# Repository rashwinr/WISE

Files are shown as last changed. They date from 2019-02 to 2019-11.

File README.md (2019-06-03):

# Wearable Inertial Sensors for Exergames

We are creating a wearable IMUs for ROM (range of motion) assessment and arm rehabilitation of stroke patients.

Data: The data folder consists of data sets saved from the IMU.
Arduino: All scripts relevant to the jacket are placed here.
3D model: All the IMU enclosure for the jacket are placed in this folder.

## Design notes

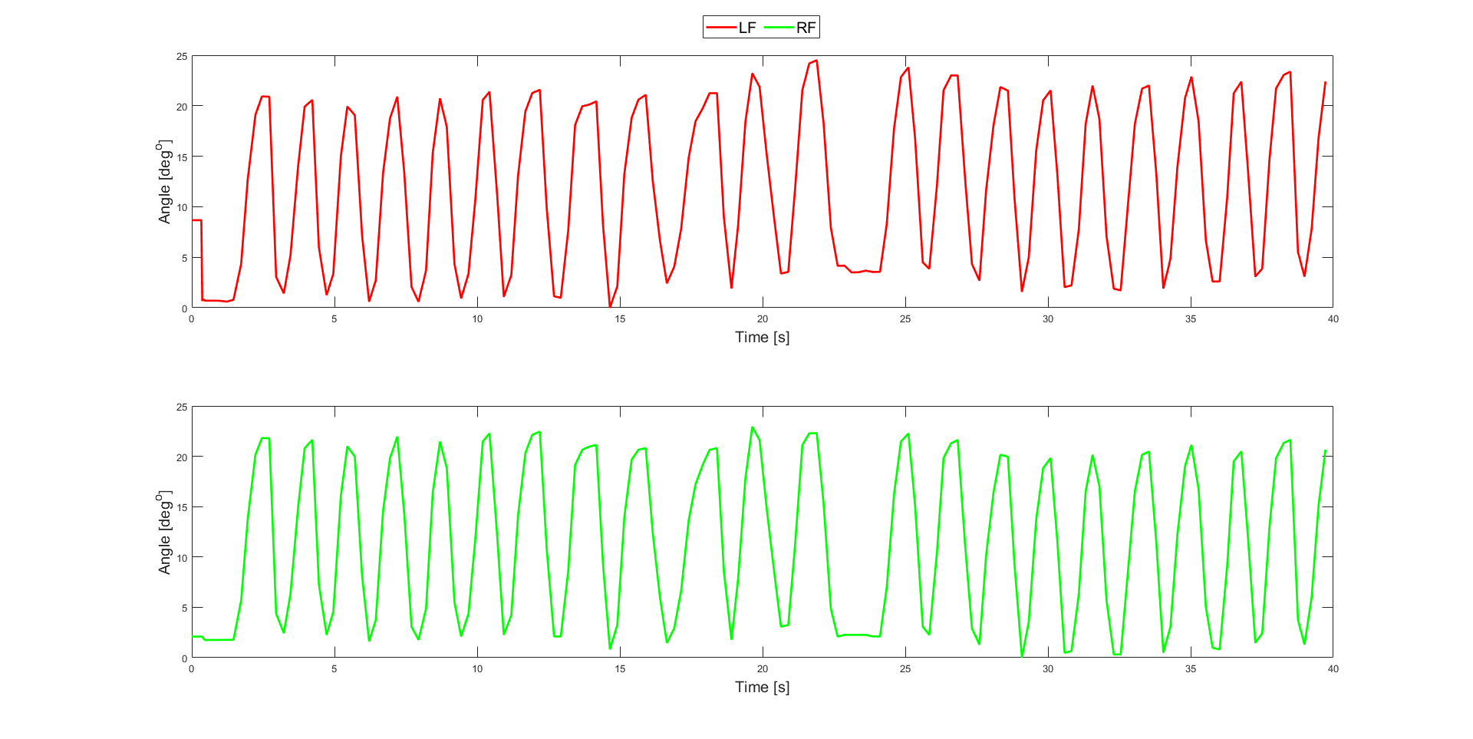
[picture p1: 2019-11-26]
matlab/IEEE_sensors/data_matched/LF,RF/Y/20 degrees.png

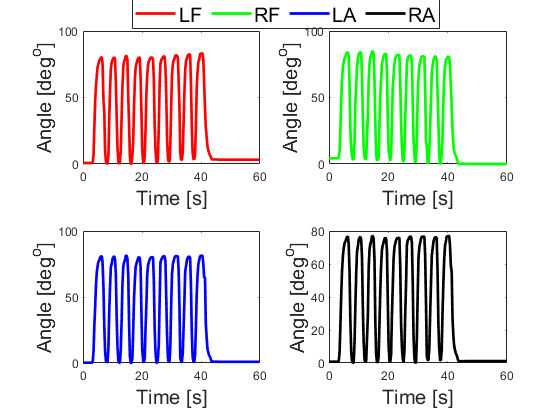
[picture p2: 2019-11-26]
matlab/IEEE_spmb/data_matched/A,B,C,D/Z/80 degress.png

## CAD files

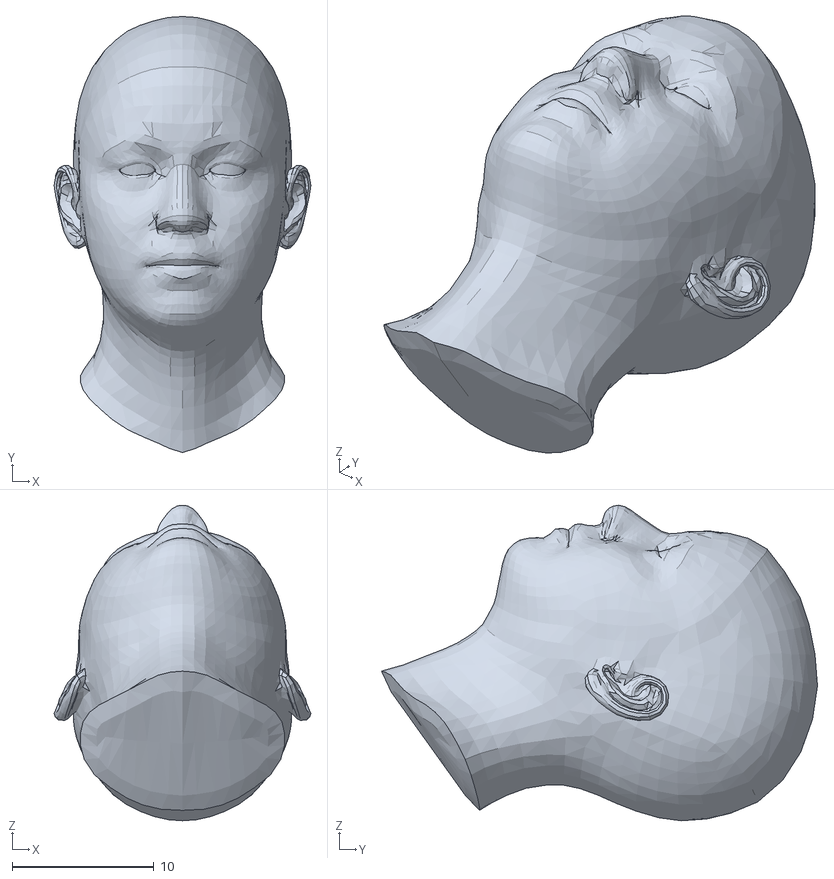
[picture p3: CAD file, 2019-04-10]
matlab/KInectProject/Kin2/Mex/NuiDatabase/HDFaceTracker/WholeHeadModel/fullMeanHead60_tri.ply
18.1 x 30.7 x 22.2

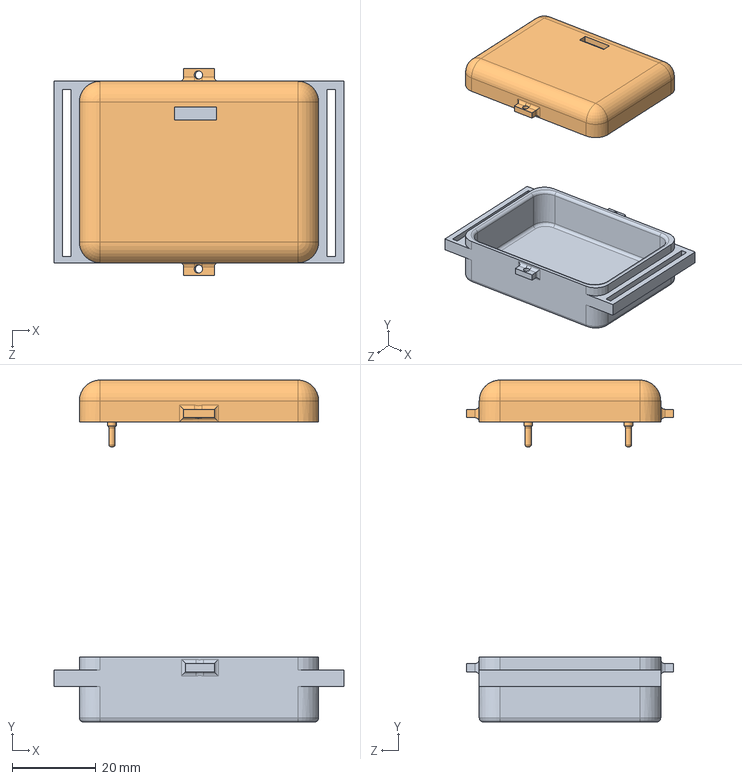
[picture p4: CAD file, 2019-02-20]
3D model/Assem1.SLDASM
69.3 x 81.9 x 49.5 mm
bottom_part_12_14_2018_Edited
top_part_12_14_2018_Edited

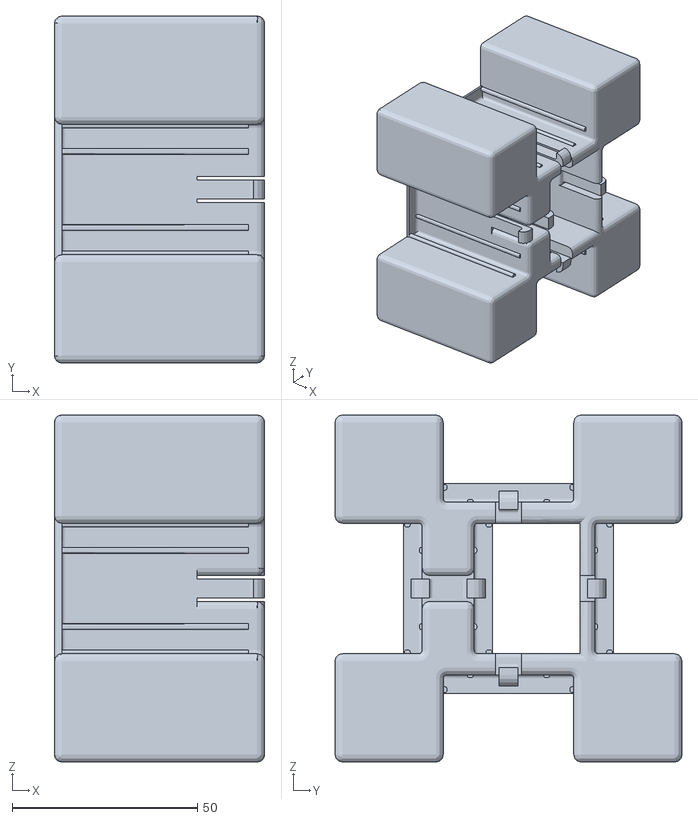
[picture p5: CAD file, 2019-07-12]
3d model final/calib_box.stl
56.7 x 93.6 x 93.6

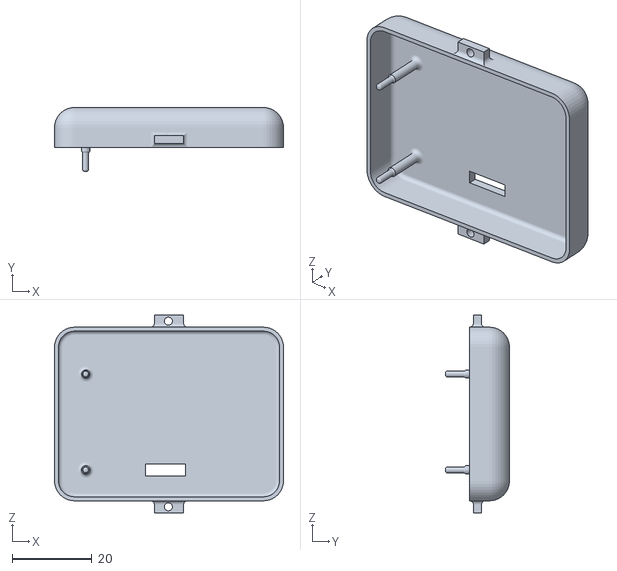
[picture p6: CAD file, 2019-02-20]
3D model/Assem1 - top_part_12_14_2018_Edited-1.STL
57.3 x 16.0 x 49.5

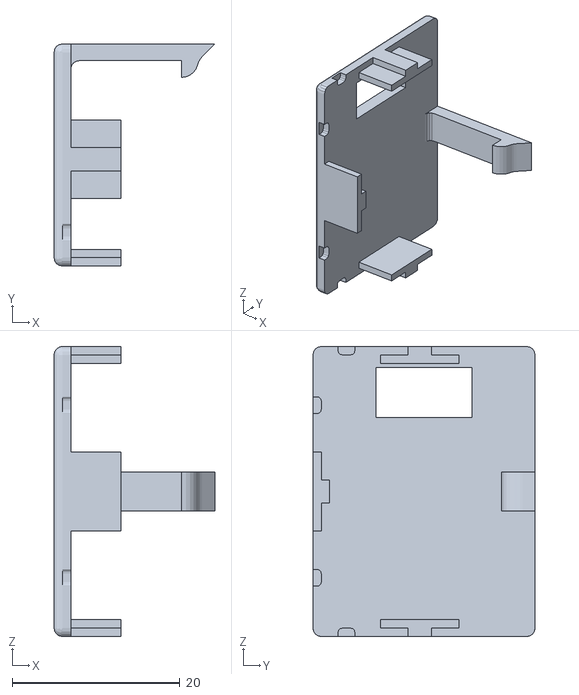
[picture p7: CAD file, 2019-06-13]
3Dmodel_ver4/door2.stl
19.2 x 26.5 x 34.6

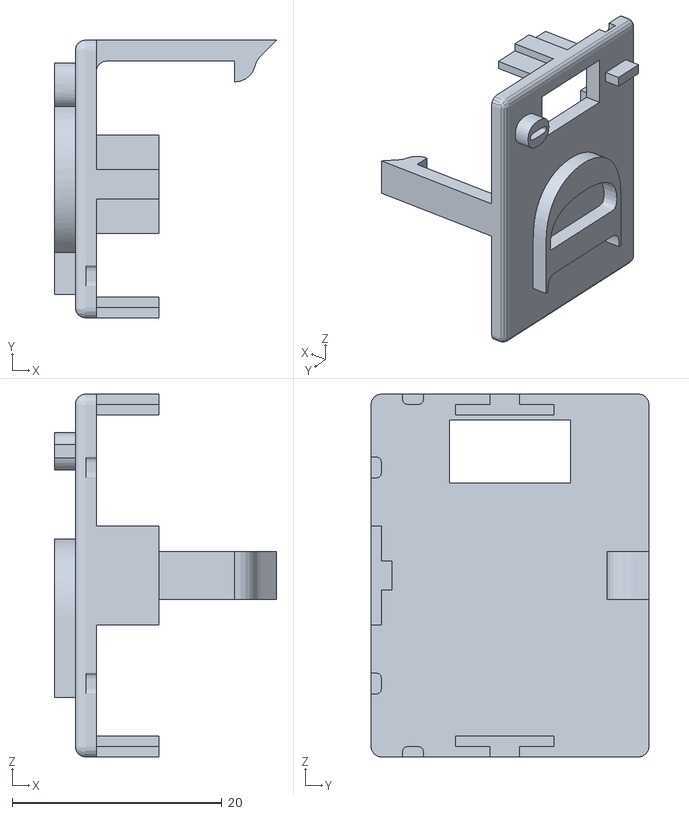
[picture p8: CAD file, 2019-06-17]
STL_4/D_door.stl
21.2 x 26.5 x 34.6

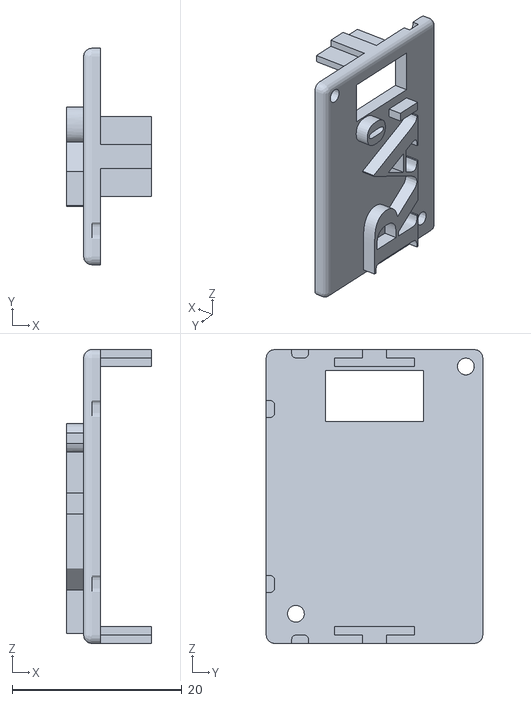
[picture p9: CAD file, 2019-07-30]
STL_4/WISE_design/door3_RA.stl
10.0 x 25.5 x 34.6

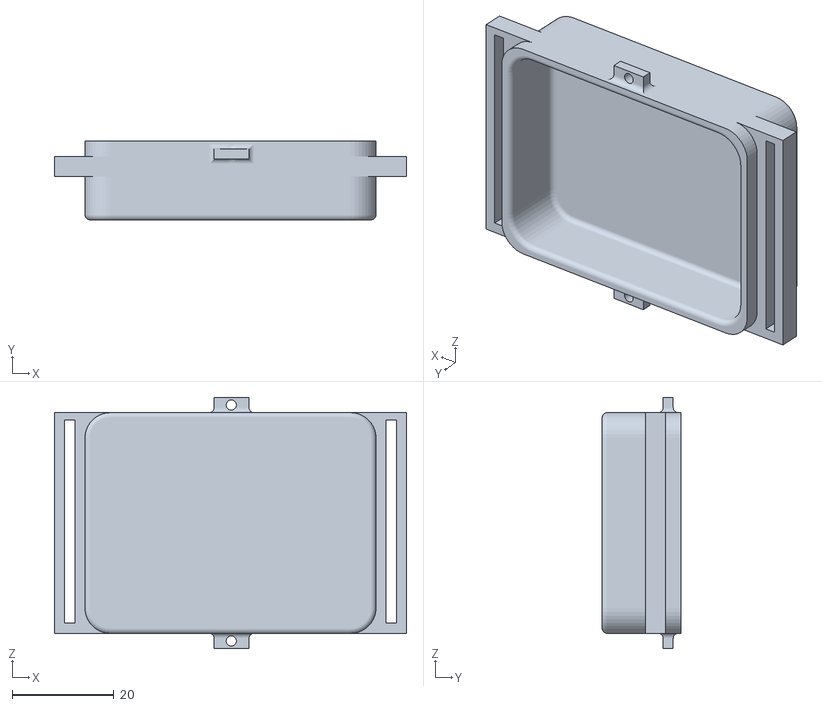
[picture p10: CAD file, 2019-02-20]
3D model/Assem1 - bottom_part_12_14_2018_Edited-1.STL
69.3 x 15.5 x 49.5

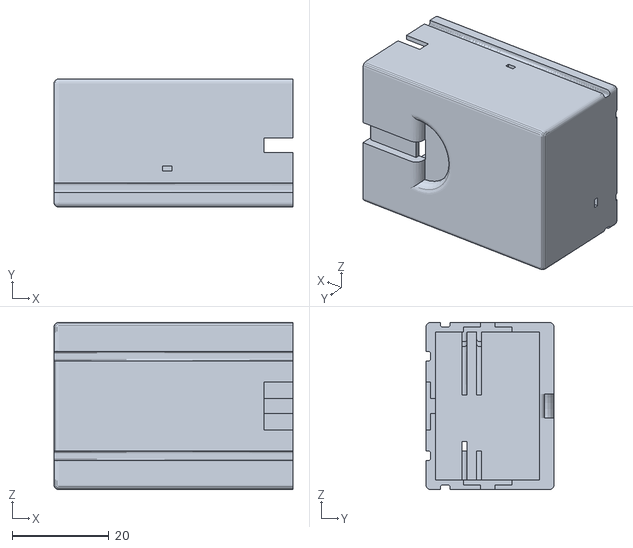
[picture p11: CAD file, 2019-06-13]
3Dmodel_ver4/case2.stl
49.4 x 26.5 x 34.6

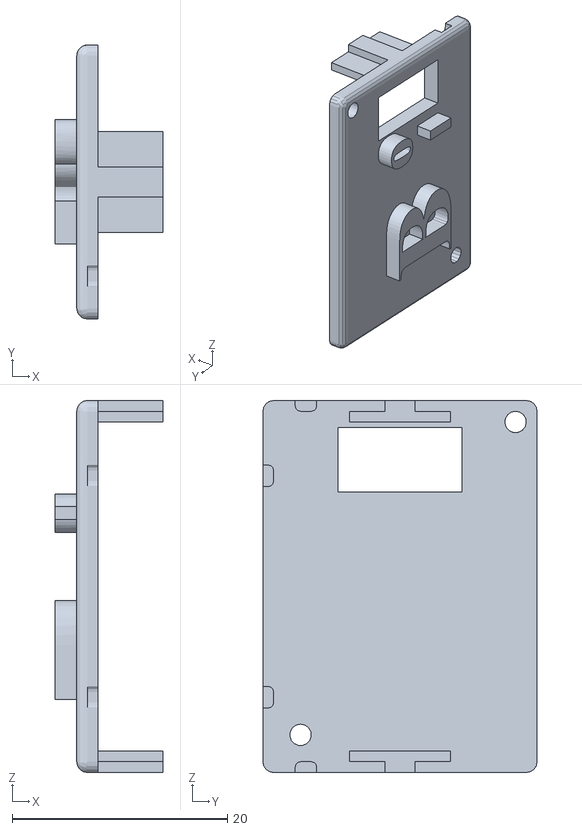
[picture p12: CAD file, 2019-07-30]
STL_4/WISE_design/door3_B.stl
10.0 x 25.5 x 34.6

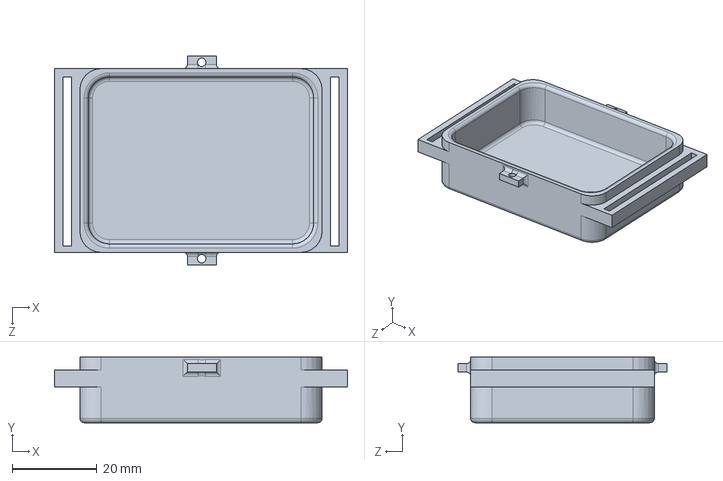
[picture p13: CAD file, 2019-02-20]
3D model/bottom_part_12_14_2018_Edited.SLDPRT
69.3 x 15.5 x 49.5 mm

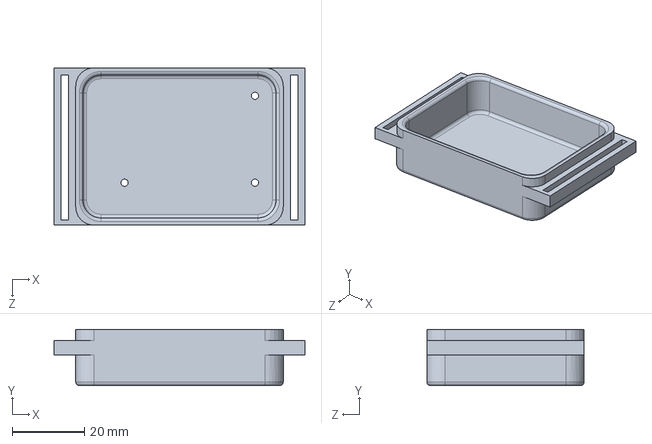
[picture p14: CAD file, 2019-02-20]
3D model/bottom_part_12_14_2018.SLDPRT
69.3 x 15.5 x 43.5 mm

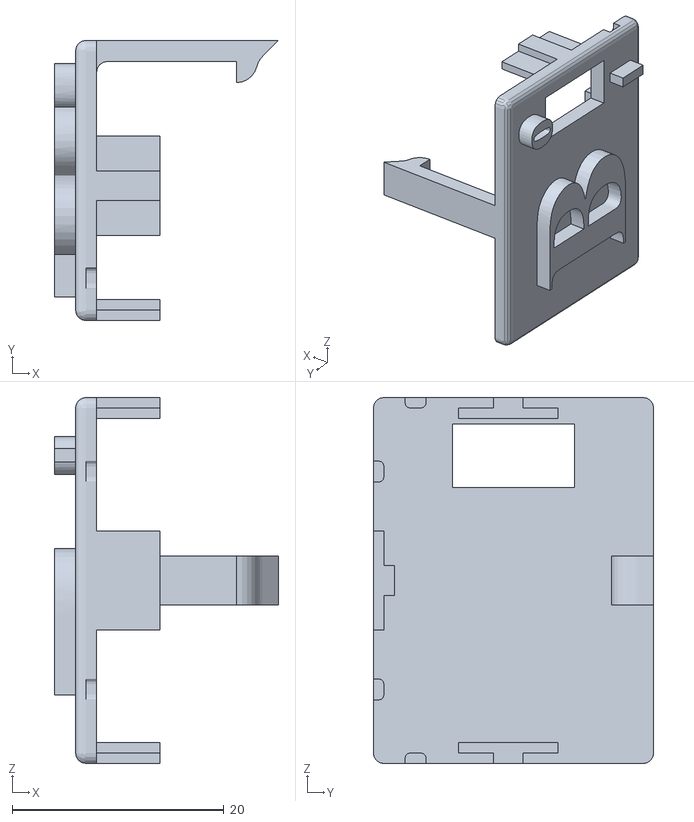
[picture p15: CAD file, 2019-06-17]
STL_4/B_door.stl
21.2 x 26.5 x 34.6

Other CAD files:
STL_4/XYZ_case.stl
STL_4/C_door.stl
STL_4/WISE_design/door3_RF.stl
STL_4/A_door.stl
STL_4/WISE_design/door3_LA.stl
3D model/bottom_part_12_14_2018.STL
3D model/bottom_part_12_14_2018_Edited.STL
3D model/top_part_12_14_2018.SLDPRT
3D model/top_part_12_14_2018.STL
3D model/top_part_12_14_2018_Edited.SLDPRT
3D model/top_part_12_14_2018_Edited.STL
3Dmodel_ver2/Assem1.SLDASM
3Dmodel_ver2/Assem1.SLDDRW
3Dmodel_ver2/bottom.SLDPRT
3Dmodel_ver2/bottom.STL
3Dmodel_ver2/box.SLDPRT
3Dmodel_ver2/calib_typ1_outsidebox.SLDPRT
3Dmodel_ver2/calibration_box.STL
3Dmodel_ver2/top.SLDPRT
3Dmodel_ver2/top.STL
3Dmodel_ver2/top_A.SLDPRT
3Dmodel_ver3/Assieme1.stl
3Dmodel_ver3/Assieme2.stl
3Dmodel_ver3/calibration_box.stl
3Dmodel_ver3/case.ipt
3Dmodel_ver3/case.stl
3Dmodel_ver3/door.ipt
3Dmodel_ver3/door.stl
3Dmodel_ver3/holderH.ipt
3Dmodel_ver3/holderH.stl
3Dmodel_ver3/holderV.ipt
3Dmodel_ver3/holderV.stl
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

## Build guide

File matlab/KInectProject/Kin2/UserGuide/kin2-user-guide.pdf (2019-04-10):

# Kin2. User Guide

### Juan R. Terven, Diana M. Cordova

## 1 Introduction

The Kin2 Toolbox for Matlab is an easy to use set of classes and functions that encapsulate the Microsoft Kinect 2 SDK. It is mostly based on C++ through mex files. The current version contains two classes and 30 functions divided in different features such as coordinate mapping, skeleton tracking, 3D reconstruc-

tion, and face gestures recognition.

## 2 Image Acquisition

Kinect three provides three sources of video images: RGB, depth, and infrared.

### The resolution of the RGB images is 1920 × 1080, the depth and infrared have

resolution of 512 × 424.

### The first step is to generate a Kin2 object specifying the image sources we

wish to obtain from the Kinect2. The available sources are color, depth,

### infrared and body. For example:

k2 = Kin2('color', 'depht', 'infrared')

### generates a Kin2 object named k2 that we can use to gather color, depth and/or

infrared frames from the Kinect2.

### To extract frames from the Kinect cameras we call the updateKin2 function on the Kin2 object. For example:

validData = k2.updateKin2

### Note that this function gets data from the Kinect and save it in an internal buffer

in Matlab. If there was a valid frame, the function returns 1 if not, returns 0.

### To actually get the frames in Matlab variables we call the corresponding

functions on the Kin2 object: getDepth, getColor, and getInfrared.

### Listing 1.1 shows how to create a Kin2 object to gather and display video from these three sources. In this example, we created we three figures, one for

each source and update the content each valid frame.

Listing 1.1. Kin2 initialization and data acquisition

1 | clear all
2 | % Create Kinect 2 object and initialize it
3 | % Select sources as input parameters.
4 | % Available sources: 'color', 'depth', 'infrared' and 'body'
5 | k2 = Kin2('color','depth','infrared');

6
7 % Create the figures for the images

8 | figure, h1 = imshow(zeros(424,512,'uint16'),[0 4000]);
9 | colormap('Jet'), colorbar;
10 | figure, h2 = imshow(zeros(1080,1920,3,'uint8'),[]);
11 | figure, h3 = imshow(zeros(424,512,'uint16'),[0 8000]);
12 | set(gcf,'keypress','k=get(gcf,''currentchar'');');

13
14 | % Loop until pressing 'q' on infrared figure
15 | k=[];
16 | while true
17 | % Read frames from Kinect
18 | validData = k2.updateData;

19
20 | % Before accessing the data,
21 | % make sure that a valid frame was acquired.
22 | if validData
23 | depth = k2.getDepth;
24 | color = k2.getColor;
25 | infrared = k2.getInfrared;

26
27 | set(h1,'CData',depth);
28 | set(h2,'CData',color);
29 | set(h3,'CData',infrared);
30 | end

31
32 | % If user presses 'q', on the infrared figure exit loop
33 | if ¬isempty(k)
34 | if strcmp(k,'q'); break; end;
35 | end

36
37 | pause(0.02)
38 | end

39
40 close all

41
42 | % Close kinect object
43 | k2.delete;

## 3 Coordinate Mapping

### Coordinate Mapping is used to perform two tasks [1]: (1) map between locations on the depth image and their corresponding locations on the color image and viceversa and (2) project and unproject from 2D image space to 3D camera

space. 2D image space refers to the depth or color image coordinates.

### In practice, to perform any mapping, you should always update the Kin2 data calling updateKin2 on the Kin2 object and see if there are valid data as

shown in listing 1.

### 3.1 Depth Space

### In depth space, x = 1, y = 1 corresponds to the top left corner of the image and x = 512, y = 424 is the bottom right corner of the image. When we need the

depth value or z, simply sample the depth image at the row/column in question,

### and use that value as z (in millimeters). For example: if depth is a depth image

obtained with getDepth, we get the depth as z = depth(row,col).

### Map Depth to Color The color sensor and depth sensor have a small offset between each other and different resolutions. To map between locations on the depth image and their corresponding locations on the color image Kin2 provides the function

ptColor = k2.mapDepthPoints2Color(ptDepth)
where ptColor and ptDepth are a n × 2 matrix of image coordinates.
For a complete code example see the mapping demo in section 7.1.

Map Depth to Camera and Point Cloud A common operation on the depth image is to generate a 3D point cloud of the scene. For this, Kin2 provides a couple of methods. The first one consists of mapping a set of coordinates from depth space to camera space for example. This method is useful if you only need to map few points from depth space to camera space:

ptCam = k2.mapDepthPoints2Camera(ptDepth)

### where ptDepth is a n×2 matrix (n x,y coordinates), and ptCam is n×3 matrix

(n x,y,z coordinates).

### If you want to get the complete point cloud, i.e. to map all the points from depth space to camera space, Kin2 provides:

pointCloud = k2.getPointCloud

### where pointcloud is a N × 3 camera space values. And N = 512 × 424 = 217088. Note that coordinates with no depth information can not be mapped to

camera space, and these coordinates are return as inf or -inf in camera space.

### For a complete code example see the camera mapping demo in section 7.3

and the point cloud demo in section 7.2.

### Map Depth to Infrared Depth and infrared images come from the same sensor so there is no offset and no change in resolution. To map a point from

depth to infrared just sample the same coordinates.

### 3.2 Color Space

In color space, x = 1, y = 1 corresponds to the top left corner of the image and x = 1920, y = 1080 is the bottom right corner of the image. A common practice in RGBD processing is to obtain the depth or world coordinates of specific color space coordinates. For example if we find features in the color image and we

want to know their depth or location in the world.

### Map Color to Depth Kin2 provides the following function to map from color

space to depth space.

ptDepth = k2.mapColorPoints2Depth(ptColor)
where ptColor and ptDepth are a n × 2 matrix of image coordinates.
For a complete code example see the mapping demo in section 7.1.

### Map Color to Camera Kin2 also provides a function to map from color space

to camera space.

ptCam = k2.mapColorPoints2Camera(ptColor)

### where ptColor is a n×2 matrix (n x,y coordinates), and ptCam is n×3 matrix

(n x,y,z coordinates).
For a complete code example see the camera mapping demo in section 7.3.

### 3.3 Camera Space

Camera space refers to the 3D coordinate system (right-handed) used by Kinect.

### The coordinate system is defined as follows [1]:

### – The origin (x=0, y=0, z=0) is located at the center of the IR sensor on

Kinect.

### – X grows to the sensors left – Y grows up (note that this direction is based on the sensors tilt) – Z grows out in the direction the sensor is facing – 1 unit = 1 meter

### Kinect2 SDK provides mapping capabilities between camera space and depth

or color space that is 2D projections.

### Map Camera to Depth Kin2 provides a function to map from 3D camera coordinates to depth image coordinates:

ptDepth = k2.mapCameraPoints2Depth(ptCam)

### where ptCam is n × 3 matrix (n x,y,z coordinates) and ptDepth is a n × 2

matrix (n x,y coordinates).
For a complete code example see the camera mapping demo in section 7.3.

### Map Camera to Color Kin2 also provides a function to map from 3D camera

coordinates to color image coordinates.

ptColor = k2.mapCameraPoints2Color(ptCam)

### where ptCam is n × 3 matrix (n x,y,z coordinates) and ptColor is a n × 2

matrix (n x,y coordinates).
For a complete code example see the camera mapping demo in section 7.3.

## 4 Body Tracking

Kin2 provides easy access to Kinect 2 body tracking capabilities.

### To enable body tracking, you must indicate the body source when creating the Kin2 object. For example:

k2 = Kin2(’color’,’depth’,’body’)

### creates a Kin2 object capable of fetching color and depth frames and also body

tracking information.

### Then to get the body data Kin2 provides the function getBodies that you can call after updating the Kin2 data. For example:

bodies = k2.getBodies

### where bodies is a structure array with one element for each body (6 bodies maximum). Each element contains the following information:

### – Position: a 3x25 matrix containing the x,y,z of the 25 joints in camera space coordinates

– TrackingState: state of each joint. These can be: NotTracked=0, Inferred=1,

### or Tracked=2 – LeftHandState: state of the left hand – RightHandState: state of the right hand

### The RightHandState and LeftHandState properties provide information about the state of each of the player’s hands. You can use this information to determine if a player is interacting with an object in the title’s world [2]. The states

returned are: Open, Closed, Lasso, NotTracked, Unknown.

### Once you have the joints position in 3D space you can map them to depth or

color space for visualization using the mapCameraPoints2Depth or mapCameraPoints2Color

### functions described in section 3.3, for example:

posDepth = k2.mapCameraPoints2Depth(bodies(1).Position’)
posColor = k2.mapCameraPoints2Color(bodies(1).Position’)
For a complete example of body tracking see section 7.4.

### 4.1 Drawing Bodies

### Kin2 provides functions to draw the bodies on the depth image or the color

image freeing the developer from this tedious task.

### To draw bodies on depth or color image you can use the drawBodies function as follows:

k2.drawBodies(d.ax,bodies,’depth’,5,3,15)

### where the six parameters are the following:

1. Image axes. Figure axes obtained with Matlab axes function.
2. Bodies structure. Bodies returned by the getBodies function.
3. Destination image. ’depth’ or ’color’.
4. Joints’ size. Circle raddii.
5. Bones’ Thickness.
6. Hands’ Size.

For a complete example of body tracking and drawing see section 7.4.

## 5 Face Processing

Kin 2 provides two levels of face processing: simple face processing and HD face.

### 5.1 Simple Face Processing

### With this functionality We can detect and track the face and recognize eight facial properties listed in table 1. The getFaces method returns a MATLAB structure array containing the following face data for each detected face:

– FaceBox: rectangle containing the user’s face.
– FacePoints: five alignment points located on the user’s face.
– FaceRotation: face orientation expressed as Euler angles: pitch, yaw, roll.

### – FaceProperties: read-only key/value pairs. See Table 1 for a description

of each property. Each property can have the following values: Unknown,
No, Maybe, or Yes.

Table 1. Face Properties contained in the FaceProperties field of the structure array returned with getFaces.

Name | Description
Happy | The user is showing a smile.

Engaged

Combines results from Looking Away and Eye Closed to determine if user is engaged with content.

WearingGlasses | The user is wearing glasses.
LeftEyeClosed | The user’s left eye is closed.
RightEyeClosed | The user’s right eye is closed.
MouthOpen | The user’s mouth is open.
MouthMoved | The user’s mouth moved
LookingAway | Determines if the user is looking away from the content

### 5.2 HD Face Processing

HD Face provides amazing face processing capabilities: (1) face capture with 94 shape units and a high definition face model with 1347 mesh vertices, (2) face tracking of 17 animation units (AUs) expressed as a numeric weight varying between 0 and 1. Kin2 provides access to these HD face capabilities with the getHDFaces method. This method returns a structure array containing the following fields for each detected face:

– FaceBox: rectangle containing the user’s face.
– FaceRotation: face orientation expressed as Euler angles: pitch, yaw, roll.

### – HeadPivot: center of the head, which the face may be rotated around. The origin is located at the Kinect’s optical center, the Z axis is pointing towards a user, the Y axis is pointing up and the X axis is pointing to the right. The

units are in meters.

### – AnimationUnits: 17 animation units (AUs) expressed as a numeric weight

varying between 0 and 1. Refer to [3] for a list of these animation units.

### – ShapeUnits: 94 shape units (SUs) expressed as a numeric weight varying between -2 and +2. Refer to [4] for a list of these shape units, also called

shape deformations.

### – FaceModel: high definition face model with 1347 mesh vertices. Refer to [5]

for a list of these high detail face points.

## 6 3D Reconstruction

### The Kin2 toolbox includes a version of Kinect Fusion taken from the Kinect for Windows SDK 2.0. To initialize the 3D reconstruction engine, Kin2 provides the method KF init that can be configured for different reconstruction’s resolution and size. The method prototype is the following:

KF init(voxelsPerMeter,voxelsX,voxelsY,voxelsZ,gpu)

For example if we set voxelsPerMeter to 256 we will have a resolution of 1000mm ÷ 256vpm = 3.9mm/voxel, then if we set voxelsX, voxelsY, and voxelsZ to 384 we will have a reconstruction of 384voxels ÷ 256vpm = 1.5m wide reconstruction and we will require at least 384 × 384 × 384 × 4 bytes per voxel = 227MB of memory. The final parameter gpu if true, the algorithm will

use the GPU otherwise, it will use the CPU.

### Once initialized, each call to KF update updates the volume reconstruction

with new views.

## 7 Complete Code examples

### 7.1 Mapping Demo

1 % MAPPINGDEMO Illustrates how to map points between depth ... and color images

2 | %
3 | % Usage:
4 | % | - Press 'd' to select 5 points on the depth image. ...
| | The selected points
5 | % | will be mapped from depth to color and will be ...
| | displayed on both
6 | % | images in red.

7 | % | - Press 'c' to select 5 point on the color image. The ...
| | selected points
8 | % | will be mapped from color to depth and will be ...
| | displayed on both
9 | % | images in green.
10 | % | - Press 'q' to exit.
11 | %
12 | % Juan R. Terven, October 2015.
13 | % jrterven@hotmail.com

14
15 | addpath('Mex');
16 | clear all
17 | close all

18
19 | % Create a Kin2 object and initialize it
20 | % Select sources as input parameters.
21 | % Available sources: 'color', 'depth', 'infrared' and 'body'
22 | k2 = Kin2('color','depth');

23
24 | % images sizes
25 | d_width = 512; d_height = 424; outOfRange = 4000;
26 | c_width = 1920; c_height = 1080;

27
28 | % Color image is to big, let's scale it down
29 | COL_SCALE = 0.5;

30
31 | % Create matrices for the images
32 | depth = zeros(d_height,d_width,'uint16');
33 | color = ...
| | zeros(c_height*COL_SCALE,c_width*COL_SCALE,3,'uint8');

34
35 | % Images used to draw the markers
36 | depthAdditions = zeros(d_height,d_width,3,'uint8');
37 | colorAdditions = ...
| | zeros(c_height*COL_SCALE,c_width*COL_SCALE,3,'uint8');

38
39 | % depth stream figure
40 | d.h = figure;
41 | d.ax = axes('units','pixels','drawmode','fast');
42 | d.im = imshow(depth,[0 255]);
43 | title('Depth Source (press q to exit)')
44 | set(gcf,'keypress','k=get(gcf,''currentchar'');'); % ...
| | listen keypress

45
46 | % color stream figure
47 | c.h = figure;
48 | c.im = imshow(color,[]);
49 | title('Color Source (press q to exit)');
50 | set(gcf,'keypress','k=get(gcf,''currentchar'');'); % ...
| | listen keypress

51

52
53 | % Loop until pressing 'q' on any figure
54 | k=[];

55
56 | disp('Instructions:')
57 | disp('Press d to select a point on the depth image')
58 | disp('Press c to select a point on the color image')
59 | disp('Press q on any figure to exit')

60
61 | while true
62 | % Get frames from Kinect and save them on underlying ...
| buffer
63 | validData = k2.updateData;

64
65 | % Before processing the data, we need to make sure ...
| that a valid
66 | % frame was acquired.
67 | if validData
68 | % Copy data to Matlab matrices
69 | depth = k2.getDepth;
70 | color = k2.getColor;

71
72 | % update depth figure
73 | depth8u = uint8(depth*(255/outOfRange));
74 | depth8uc3 = repmat(depth8u,[1 1 3]);
75 | set(d.im,'CData',depth8uc3 + depthAdditions);

76
77 | % update color figure
78 | color = imresize(color,COL_SCALE);
79 | set(c.im,'CData',color + colorAdditions);
80 | end

81
82 | % If user presses 'd' enter to points selection mode ...
| on the depth image
83 | % If user presses 'c' enter to points selection mode ...
| on the color image
84 | % If user presses 'q', exit loop
85 | if ¬isempty(k)
86 | if strcmp(k,'d')
87 | figure(d.h);
88 | title('Clic the image to sample 5 points');

89
90 | % Grab 5 points
91 | [x,y] = ginput(5);
92 | disp('Input depth coordinates');
93 | disp([x y])
94 | % Draw the selected points in the depth image

95 | depthAdditions = ...
| insertMarker(depthAdditions,[x ...
| y],'Color','red');

96
97 | % Using the mapping, map the points from ...
| depth coordinates to color coordinates
98 | % Input and output: n x 2 matrix (n points)
99 | colorCoords = k2.mapDepthPoints2Color([x y]);
100 | colorCoords = colorCoords * COL_SCALE; % ...
| scale the color coordinates

101
102 | disp('Output color coordinates');
103 | disp(colorCoords);

104
105 | % Draw the output coordinates on the color image
106 | colorAdditions = insertMarker(colorAdditions, ...
| colorCoords,'Color','red','Size',10);

107
108 | k = [];
109 | elseif strcmp(k,'c')
110 | figure(c.h);
111 | title('Clic the image to sample 5 points');

112
113 | % Grab 5 points
114 | [x,y] = ginput(5);
115 | disp('Input color coordinates');
116 | disp([x y]);

117
118 | % Draw the selected points in the color image
119 | colorAdditions = ...
| insertMarker(colorAdditions,[x ...
| y],'Color','green','Size',5);

120
121 | % Using the mapping, map the points from ...
| color coordinates to depth coordinates
122 | % Input and output: n x 2 matrix (n points)
123 | depthCoords = ...
| k2.mapColorPoints2Depth([x/COL_SCALE ...
| y/COL_SCALE]);

124
125 | disp('Output depth coordinates')
126 | disp(depthCoords);

127
128 | % Drae the output coordinates on the depth image
129 | depthAdditions = ...
| insertMarker(depthAdditions,depthCoords,'Color','green');

130

131
132 | k = [];
133 | end

134
135 | if strcmp(k,'q'); break; end;
136 | end

137
138 | pause(0.02)
139 | end

140
141 | % Close kinect object
142 | k2.delete;

143
144 close all

### 7.2 Point Cloud Demo

1 | % POINTCLOUDDEMO Illustrates how to use the Kin2 class to ...
| get the
2 | % pointcloud in camera space
3 | %
4 | % Juan R. Terven, January 2016.
5 | % jrterven@hotmail.com

6
7 | addpath('Mex');
8 | clear all
9 | close all

10
11 | % Create Kinect 2 object and initialize it
12 | % Select sources as input parameters.
13 | % Available sources: 'color', 'depth', 'infrared' and 'body'
14 | k2 = Kin2('depth');

15
16 | % images sizes
17 | depth_width = 512; depth_height = 424; outOfRange = 4000;

18

19
20 | % Create matrices for the images
21 | depth = zeros(depth_height,depth_width,'uint16');
22 | pointCloud = zeros(depth_height*depth_width,3);

23
24 | % depth stream figure
25 | figure, h1 = imshow(depth,[0 outOfRange]);
26 | title('Depth Source (press q to exit)')
27 | colormap('Jet')
28 | colorbar
29 | set(gcf,'keypress','k=get(gcf,''currentchar'');'); % ...
| listen keypress

30
31 % point cloud figure

32 | figure, hpc = ...
| plot3(pointCloud(:,1),pointCloud(:,2),pointCloud(:,3),'.');
33 | title('Point Cloud (press q to exit)')
34 | axis([-3 3 -3 3 0 4])
35 | xlabel('X'), ylabel('Y'), zlabel('Z');
36 | set(gcf,'keypress','k=get(gcf,''currentchar'');'); % ...
| listen keypress

37
38 | % Loop until pressing 'q' on any figure
39 | k=[];

40
41 | disp('Press q on any figure to exit')
42 | while true
43 | % Get frames from Kinect and save them on underlying ...
| buffer
44 | validData = k2.updateData;

45
46 | % Before processing the data, we need to make sure ...
| that a valid
47 | % frame was acquired.
48 | if validData
49 | % Copy data to Matlab matrices
50 | depth = k2.getDepth;

51
52 | % update depth figure
53 | depth(depth>outOfRange) = outOfRange; % truncate ...
| depht
54 | set(h1,'CData',depth);

55
56 | pointCloud = k2.getPointCloud;
57 | set(hpc,'XData',pointCloud(:,1),'YData',pointCloud(:,2),'ZData',pointCloud(:,3));

58
59 | end

60
61 | % If user presses 'q', exit loop
62 | if ¬isempty(k)
63 | if strcmp(k,'q');
64 | break;
65 | elseif strcmp(k,'p');
66 | pause;
67 | end;
68 | end

69
70 | pause(0.02)
71 | end

72
73 | % Close kinect object
74 | k2.delete;

75
76 close all;

### 7.3 Camera Mapping Demo

1 % MAPPINGTOCAMDEMO Illustrates how to map points between ... depth and color images

2 | %
3 | % Usage:
4 | % | - Press 'd' to select a point on the depth image. The ...
| | selected point
5 | % | will be mapped from depth to camera and the ...
| | resulting coordinates are
6 | % | printed on command window. Then the camera ...
| | coordinates are mapped
7 | % | back to depth space and printed to command window.
8 | % | - Press 'c' to select a point on the color image. The ...
| | selected point
9 | % | will be mapped from color to camera and the ...
| | resulting coordinates are
10 | % | printed on command window. | Then the camera ...
| | coordinates are mapped
11 | % | back to color space and printed to command window.
12 | % | - Press 'q' to exit.
13 | %
14 | % Juan R. Terven, October 2015.
15 | % jrterven@hotmail.com

16
17 | addpath('Mex');
18 | clear all
19 | close all

20
21 | % Create Kinect 2 object and initialize it
22 | % Select sources as input parameters.
23 | % Available sources: 'color', 'depth', 'infrared' and 'body'
24 | k2 = Kin2('color','depth');

25
26 | % images sizes
27 | depth_width = 512; depth_height = 424; outOfRange = 4000;
28 | color_width = 1920; color_height = 1080;

29
30 | % Color image is to big, let's scale it down
31 | COL_SCALE = 0.5;

32
33 | % Create matrices for the images
34 | depth = zeros(depth_height,depth_width,'uint16');
35 | color = ...
zeros(color_height*COL_SCALE,color_width*COL_SCALE,3,'uint8');

36
37 | % Images used to draw the markers
38 | depthAdditions = zeros(depth_height,depth_width,3,'uint8');
39 | colorAdditions = ...
| zeros(color_height*COL_SCALE,color_width*COL_SCALE,3,'uint8');

40
41 | % depth stream figure
42 | h1 = figure;
43 | hdepth = imshow(depth,[0 255]);
44 | title('Depth Source (press q to exit)')
45 | set(gcf,'keypress','k=get(gcf,''currentchar'');'); % ...
| listen keypress

46
47 | % color stream figure
48 | h2 = figure;
49 | hcolor = imshow(color,[]);
50 | title('Color Source (press q to exit)');
51 | set(gcf,'keypress','k=get(gcf,''currentchar'');'); % ...
| listen keypress

52

53
54 | % Loop until pressing 'q' on any figure
55 | k=[];

56
57 | disp('Instructions:')
58 | disp('Press d to select a point on the depth image')
59 | disp('Press c to select a point on the color image')
60 | disp('Press q on any figure to exit')

61
62 | while true
63 | % Get frames from Kinect and save them on underlying ...
| buffer
64 | validData = k2.updateData;

65
66 | % Before processing the data, we need to make sure ...
| that a valid
67 | % frame was acquired.
68 | if validData
69 | % Copy data to Matlab matrices
70 | depth = k2.getDepth;
71 | color = k2.getColor;

72
73 | % update depth figure
74 | depth8u = uint8(depth*(255/outOfRange));
75 | depth8uc3 = repmat(depth8u,[1 1 3]);
76 | set(hdepth,'CData',depth8uc3 + depthAdditions);

77
78 | % update color figure
79 | color = imresize(color,COL_SCALE);
80 | set(hcolor,'CData',color + colorAdditions);

81 | end

82
83 | % If user presses 'd' enter to points selection mode ...
| on the depth image
84 | % If user presses 'c' enter to points selection mode ...
| on the color image
85 | % If user presses 'q', exit loop
86 | if ¬isempty(k)
87 | if strcmp(k,'d')
88 | figure(h1);
89 | title('Clic the image to sample a point');

90
91 | % Grab 1 points
92 | [x,y] = ginput(1);
93 | disp('Input depth coordinates');
94 | disp([x y])
95 | % Draw the selected points in the depth image
96 | depthAdditions = ...
| insertMarker(depthAdditions,[x ...
| y],'Color','red');

97
98 | % Map the point from depth coordinates to ...
| camera coordinates
99 | % Input: 1 x 2 matrix (1 points, x,y)
100 | % Output: 1 x 3 matrix (1 point, x,y,z)
101 | camCoords = k2.mapDepthPoints2Camera([x y]);

102
103 | disp('Mapped camera coordinates');
104 | disp(camCoords);

105
106 | % Map the resulting camera point back to ...
| depth space
107 | depthCoords = ...
| k2.mapCameraPoints2Depth(camCoords);
108 | disp('Mapped depth coordinates');
109 | disp(depthCoords);

110
111 | k = [];
112 | elseif strcmp(k,'c')
113 | figure(h2);
114 | title('Clic the image to sample 5 points');

115
116 | % Grab 1 point
117 | [x,y] = ginput(1);
118 | disp('Input color coordinates');
119 | disp([x/COL_SCALE y/COL_SCALE]);

120
121 | % Draw the selected point in the color image

122 | colorAdditions = ...
| insertMarker(colorAdditions,[x ...
| y],'Color','green','Size',5);

123
124 | % Map the points from color coordinates to ...
| camera coordinates
125 | % Input: 1 x 2 matrix (1 points, x,y)
126 | % Output: 1 x 3 matrix (1 point, x,y,z)
127 | camCoords = ...
| k2.mapColorPoints2Camera([x/COL_SCALE ...
| y/COL_SCALE]);

128
129 | disp('Mapped camera coordinates')
130 | disp(camCoords);

131
132 | % Map the resulting camera point back to ...
| color space
133 | colorCoords = ...
| k2.mapCameraPoints2Color(camCoords);
134 | disp('Mapped color coordinates');
135 | disp(colorCoords);

136
137 | k = [];
138 | end

139
140 | if strcmp(k,'q'); break; end;
141 | end

142
143 | pause(0.02)
144 | end

145
146 | % Close kinect object
147 | k2.delete;

148
149 close all

### 7.4 Body Tracking Demo

1 | % BODYDEMO Illustrates how to use the Kin2 object to get ...
| and draw the
2 | % Skeleton data
3 | %
4 | % Juan R. Terven, October 31 2015.
5 | % jrterven@hotmail.com

6
7 | addpath('Mex');
8 | clear all

9 close all

10
11 | % Create Kinect 2 object and initialize it
12 | % Select sources as input parameters.
13 | % Available sources: 'color', 'depth', 'infrared' and 'body'
14 | k2 = Kin2('color','depth','body');

15
16 | % images sizes
17 | d_width = 512; d_height = 424; outOfRange = 4000;
18 | c_width = 1920; c_height = 1080;

19
20 | % Color image is to big, let's scale it down
21 | COL_SCALE = 1.0;

22
23 | % Create matrices for the images
24 | depth = zeros(d_height,d_width,'uint16');
25 | color = ...
| zeros(c_height*COL_SCALE,c_width*COL_SCALE,3,'uint8');

26
27 | % depth stream figure
28 | d.h = figure;
29 | d.ax = axes('drawmode','fast');
30 | d.im = imshow(zeros(d_height,d_width,'uint8'));
31 | %hold on;

32
33 | title('Depth Source (press q to exit)')
34 | set(gcf,'keypress','k=get(gcf,''currentchar'');'); % ...
| listen keypress

35
36 | % color stream figure
37 | c.h = figure;
38 | c.ax = axes;
39 | c.im = imshow(color,[]);
40 | title('Color Source (press q to exit)');
41 | set(gcf,'keypress','k=get(gcf,''currentchar'');'); % ...
| listen keypress
42 | %hold on

43
44 | % Loop until pressing 'q' on any figure
45 | k=[];

46
47 | disp('Press q on any figure to exit')
48 | while true
49 | % Get frames from Kinect and save them on underlying ...
| buffer
50 | validData = k2.updateData;

51
52 | % Before processing the data, we need to make sure ...
| that a valid
53 | % frame was acquired.

54 | if validData
55 | % Copy data to Matlab matrices
56 | depth = k2.getDepth;
57 | color = k2.getColor;

58
59 | % update depth figure
60 | depth8u = uint8(depth*(255/outOfRange));
61 | depth8uc3 = repmat(depth8u,[1 1 3]);
62 | d.im = imshow(depth8uc3, 'Parent', d.ax);

63
64 | %set(d.im,'CData',depth8uc3);

65
66 | % update color figure
67 | color = imresize(color,COL_SCALE);
68 | c.im = imshow(color, 'Parent', c.ax);

69
70 | %set(c.im,'CData',color);

71
72 | % Get 3D bodies joints
73 | % getBodies returns a structure array.
74 | % The structure array (bodies) contains 6 bodies ...
at most
75 | % Each body has:
76 | % -Position: 3x25 matrix containing the x,y,z of ...
the 25 joints in
77 | % | camera space coordinates
78 | % -TrackingState: state of each joint. These can be:
79 | % | NotTracked=0, Inferred=1, or Tracked=2
80 | % -LeftHandState: state of the left hand
81 | % -RightHandState: state of the right hand
82 | bodies = k2.getBodies;

83
84 | % Number of bodies detected
85 | numBodies = size(bodies,2);
86 | disp(['Bodies Detected: ' num2str(numBodies)])

87
88 | % first body info:
89 | %disp(bodies(1).TrackingState)
90 | %disp(bodies(1).RightHandState)
91 | %disp(bodies(1).LeftHandState)

92
93 | % To get the joints on depth image space, you can ...
| | use:
94 | %pos2D = ...
| | k2.mapCameraPoints2Depth(bodies(1).Position');

95
96 | %To get the joints on color image space, you can use:
97 | %pos2D = ...
| | k2.mapCameraPoints2Color(bodies(1).Position');

98

99 | % Draw bodies on depth image
100 | % Parameters:
101 | % 1) image axes
102 | % 2) bodies structure
103 | % 3) Destination image (depth or color)
104 | % 4) Joints' size (circle raddii)
105 | % 5) Bones' Thickness
106 | % 6) Hands' Size
107 | k2.drawBodies(d.ax,bodies,'depth',5,3,15);

108
109 | % Draw bodies on color image
110 | k2.drawBodies(c.ax,bodies,'color',10,6,30);

111

112 | end

113
114 | % If user presses 'q', exit loop
115 | if ¬isempty(k)
116 | if strcmp(k,'q'); break; end;
117 | end

118
119 | pause(0.02)
120 | end

121
122 | % Close kinect object
123 | k2.delete;

124
125 close all;

### 7.5 Face Processing Demo

1 % FACEDEMO Illustrates how to use the Kin2 object to get ... and draw the
2 | % face data
3 | %
4 | % Note: You must add to the windows path the bin ...
| | directory containing the
5 | % | Kinect20.Face.dll.
6 | % | For example: C:\Program Files\Microsoft ...
| | SDKs\Kinect\v2.0_1409\bin
7 | %
8 | % Juan R. Terven, January 2016.
9 | % jrterven@hotmail.com

10
11 | addpath('Mex');
12 | clear all
13 | close all

14

15 | % Create Kinect 2 object and initialize it
16 | % Available sources: 'color', 'depth', 'infrared', ...
'body_index', 'body',
17 | % 'face' and 'HDface'
18 | k2 = Kin2('color','face');

19
20 | % images sizes
21 | c_width = 1920; c_height = 1080;

22
23 | % Color image is to big, let's scale it down
24 | COL_SCALE = 1.0;

25
26 | % Create matrices for the images
27 | color = ...
zeros(c_height*COL_SCALE,c_width*COL_SCALE,3,'uint8');

28
29 | % color stream figure
30 | c.h = figure;
31 | c.ax = axes;
32 | c.im = imshow(color,[]);
33 | title('Color Source (press q to exit)');
34 | set(gcf,'keypress','k=get(gcf,''currentchar'');'); % ...
listen keypress

35
36 | % Loop until pressing 'q' on any figure
37 | k=[];

38
39 | disp('Press q on any figure to exit')
40 | while true
41 | % Get frames from Kinect and save them on underlying ...
buffer
42 | validData = k2.updateData;

43
44 | % Before processing the data, we need to make sure ...
that a valid
45 | % frame was acquired.
46 | if validData
47 | % Get color frame
48 | color = k2.getColor;

49
50 | % Get the faces data
51 | % faces is a structure array with at most 6 ...
| | faces. Each face has
52 | % the following fields:
53 | % - FaceBox: rectangle coordinates representing ...
| | the face position in
54 | % | color space. [left, top, right, bottom].
55 | % - FacePoints: 2 x 5 matrix representing 5 face ...
| | landmarks:

56 | % | left eye, right eye, nose, right and left ...
| | mouth corners.
57 | % - FaceRotation: 1 x 3 vector containing: pitch, ...
| | yaw, roll angles
58 | % - FaceProperties: 1 x 8 vector containing the ...
| | detection result of
59 | % | each of the face properties.
60 | % | The face properties are:
61 | % | Happy, Engaged, WearingGlasses, ...
| | LeftEyeClosed, RightEyeClosed,
62 | % | MouthOpen, MouthMoved, LookingAway
63 | % | The detection results are:
64 | % | Unknown = 0, No = 1, Maybe = 2, Yes = 3;
65 | faces = k2.getFaces;

66
67 | % update color figure
68 | color = imresize(color,COL_SCALE);
69 | c.im = imshow(color, 'Parent', c.ax);

70
71 | % Display the faces data:
72 | % Parameters:
73 | % 1) image axes
74 | % 2) faces structure obtained with getFaces
75 | % 3) face landmarks size (radius)
76 | % 4) display text information?
77 | % 5) information font size in pixels
78 | k2.drawFaces(c.ax,faces,5,true,20);

79
80 | end

81
82 | % If user presses 'q', exit loop
83 | if ¬isempty(k)
84 | if strcmp(k,'q'); break; end;
85 | end

86
87 | pause(0.02)
88 | end

89
90 | % Close kinect object
91 | k2.delete;

92
93 close all;

### 7.6 HD Face Processing Demo

1 | % FACEHDDEMO Illustrates how to use the Kin2 object to ...
| get and display the

2 | % HD face data
3 | %
4 | % Note: You must add to the windows path the bin ...
| | directory containing the
5 | % | Kinect20.Face.dll.
6 | % | For example: C:\Program Files\Microsoft ...
| | SDKs\Kinect\v2.0_1409\bin
7 | %
8 | % Juan R. Terven, January 2016.
9 | % jrterven@hotmail.com

10
11 | addpath('Mex');
12 | clear all
13 | close all

14
15 | % Create Kinect 2 object and initialize it
16 | % Available sources: 'color', 'depth', 'infrared', ...
| | 'body_index', 'body',
17 | % 'face' and 'HDface'
18 | k2 = Kin2('color','HDface');

19
20 | % images sizes
21 | c_width = 1920; c_height = 1080;

22
23 | % Color image is to big, let's scale it down
24 | COL_SCALE = 1.0;

25
26 | % Create matrices for the images
27 | color = ...
| | zeros(c_height*COL_SCALE,c_width*COL_SCALE,3,'uint8');

28
29 | % color stream figure
30 | c.h = figure;
31 | c.ax = axes;
32 | c.im = imshow(color,[]);
33 | title('Color Source (press q to exit)');
34 | set(gcf,'keypress','k=get(gcf,''currentchar'');'); % ...
| | listen keypress

35
36 | model = zeros(3,1347);
37 | figure, hmodel = plot3(model(1,:),model(2,:),model(3,:),'.');
38 | %axis([-1 1 -1 1 -1 1])
39 | title('HD Face Model (press q to exit)')
40 | xlabel('X'), ylabel('Y'), zlabel('Z');
41 | set(gcf,'keypress','k=get(gcf,''currentchar'');'); % ...
| | listen keypress

42
43 | % Loop until pressing 'q' on any figure
44 | k=[];

45

46 | disp('Press q on any figure to exit')
47 | while true
48 | % Get frames from Kinect and save them on underlying ...
buffer
49 | validData = k2.updateData;

50
51 | % Before processing the data, we need to make sure ...
that a valid
52 | % frame was acquired.
53 | if validData
54 | % Get color frame
55 | color = k2.getColor;

56
57 | % update color figure
58 | color = imresize(color,COL_SCALE);
59 | c.im = imshow(color, 'Parent', c.ax);

60
61 | % Get the HDfaces data
62 | % the output faces is a structure array with at ...
| | most 6 faces. Each face has
63 | % the following fields:
64 | % - FaceBox: rectangle coordinates representing ...
| | the face position in
65 | % | color space. [left, top, right, bottom].
66 | % - FaceRotation: 1 x 3 vector containing: pitch, ...
| | yaw, roll angles
67 | % - HeadPivot: 1 x 3 vector, computed center of ...
| | the head,
68 | % | which the face may be rotated around.
69 | % | This point is defined in the Kinect body ...
| | coordinate system.
70 | % - AnimationUnits: 17 animation units (AUs). ...
| | Most of the AUs are
71 | % | expressed as a numeric weight varying between ...
| | 0 and 1.
72 | % | For details see ... https://msdn.microsoft.com/en-us/library/microsoft.kinect.face.faceshapeanimations.aspx
73 | % - ShapeUnits: 94 hape units (SUs). Each SU is ...
| | expressed as a
74 | % | numeric weight that typically varies between ...
| | -2 and +2.
75 | % | For details see ... https://msdn.microsoft.com/en-us/library/microsoft.kinect.face.faceshapedeformations.aspx
76 | % - FaceModel: 3 x 1347 points of a 3D face model ...
| | computed by face capture
77 | faces = k2.getHDFaces;

78
79 | % Display the HD faces data and face model(1347 ...
| | points):
80 | % Parameters:

81 | % 1) image axes
82 | % 2) faces structure obtained with getFaces
83 | % 3) display HD face model vertices(1347 points)?
84 | % 4) display text information (animation units)?
85 | % 5) text font size in pixels

86

87
88 | % Plot face model points
89 | if size(faces,2) > 0
90 | model = faces(1).FaceModel;
91 | set(hmodel,'XData',model(1,:),'YData',model(2,:),'ZData',model(3,:));
92 | end
93 | end

94
95 | % If user presses 'q', exit loop
96 | if ¬isempty(k)
97 | if strcmp(k,'q'); break; end;
98 | end

99
100 | pause(0.02)
101 | end

102
103 | % Close kinect object
104 | k2.delete;

105
106 close all;

### 7.7 Kinect Fusion Demo

1 % KINECTFUSIONDEMO Illustrates how to use the Kin2 to ... perform 3D
2 | % reconstruction
3 | %
4 | % Note: You must add to the windows path the bin ...
| | directory containing the
5 | % | Kinect20.Fusion.dll
6 | % | For example: C:\Program Files\Microsoft ...
| | SDKs\Kinect\v2.0_1409\bin
7 | %
8 | % Juan R. Terven, January 2016.
9 | % jrterven@hotmail.com

10
11 | addpath('../Mex');
12 | clear all
13 | close all

14
15 % Create Kinect 2 object and initialize it

16 | % Select sources as input parameters.
17 | % Available sources: 'color', 'depth', 'infrared', ...
| 'body_index', 'body',
18 | % 'face' and 'HDface'
19 | k2 = Kin2('color','depth');

20
21 k2.KF_init;

22
23 | % images sizes
24 | depth_width = 512; depth_height = 424; outOfRange = 4000;
25 | color_width = 1920; color_height = 1080;

26
27 | % Color image is to big, let's scale it down
28 | colorScale = 0.4;

29
30 | % Create matrices for the images
31 | depth = zeros(depth_height,depth_width,'uint16');
32 | volume = zeros(depth_height,depth_width,3,'uint8');
33 | color = ...
| zeros(color_height*colorScale,color_width*colorScale,3,'uint8');

34
35 | % depth stream figure
36 | figure, h1 = imshow(depth,[0 outOfRange]);
37 | title('Depth Source (press q to exit)')
38 | colormap('Jet')
39 | colorbar
40 | set(gcf,'keypress','k=get(gcf,''currentchar'');'); % ...
| listen keypress

41
42 | % color stream figure
43 | figure, h2 = imshow(color,[]);
44 | title('Color Source (press q to exit)');
45 | set(gcf,'keypress','k=get(gcf,''currentchar'');'); % ...
| listen keypress

46
47 | % volume stream figure
48 | figure, h3 = imshow(volume,[]);
49 | title('Volume Source (press q to exit)');
50 | set(gcf,'keypress','k=get(gcf,''currentchar'');'); % ...
| listen keypress

51
52 | % Loop until pressing 'q' on any figure
53 | k=[];
54 | timedFrames = zeros(1,100);
55 | disp('Press q on any figure to exit')
56 | for i=1:100
57 | tic
58 | % Get frames from Kinect and save them on underlying ...
| buffer
59 | validData = k2.updateData;

60
61 | % Before processing the data, we need to make sure ...
that a valid
62 | % frame was acquired.
63 | if validData
64 | % Copy data to Matlab matrices
65 | depth = k2.getDepth;
66 | color = k2.getColor;

67
68 | k2.KF_update;
69 | volume = k2.KF_getVolumeImage;

70
71 | % update depth figure
72 | depth(depth>outOfRange) = outOfRange; % truncate ...
| depht
73 | set(h1,'CData',depth);

74
75 | % update color figure
76 | color = imresize(color,colorScale);
77 | set(h2,'CData',color);

78
79 | % update infrared figure
80 | set(h3,'CData',volume);
81 | end

82
83 | % If user presses 'q', exit loop
84 | if ¬isempty(k)
85 | if strcmp(k,'q'); break; end;
86 | if strcmp(k,'m');
87 | mesh = k2.KF_getMesh;
88 | k=[];
89 | end;
90 | end

91
92 | pause(0.02)
93 | timedFrames(i) = toc;
94 | end

95
96 | % Close kinect object
97 | k2.delete;

98
99 close all;

## References

1. Microsoft: | Coordinate | mapping. | https://msdn.microsoft.com/en-
us/library/dn785530.aspx (January 2016)
2. Microsoft: | Body | tracking. | https://msdn.microsoft.com/en-
us/library/dn799273.aspx (January 2016)

3. Network, | M.D.: | Faceshapeanimations | enumera-
tion. | | https://msdn.microsoft.com/en-us/library/ | mi-
crosoft.kinect.face.faceshapeanimations.aspx (January 2016)
4. Network, | M.D.: | Faceshapedeformations | enumera-
tion. | | https://msdn.microsoft.com/en-us/library/ | mi-
crosoft.kinect.face.faceshapedeformations.aspx (January 2016)
5. Microsoft: | Highdetailfacepoints enumeration. | https://msdn.microsoft.com/en-
us/library/ microsoft.kinect.face.highdetailfacepoints.aspx (January 2016)

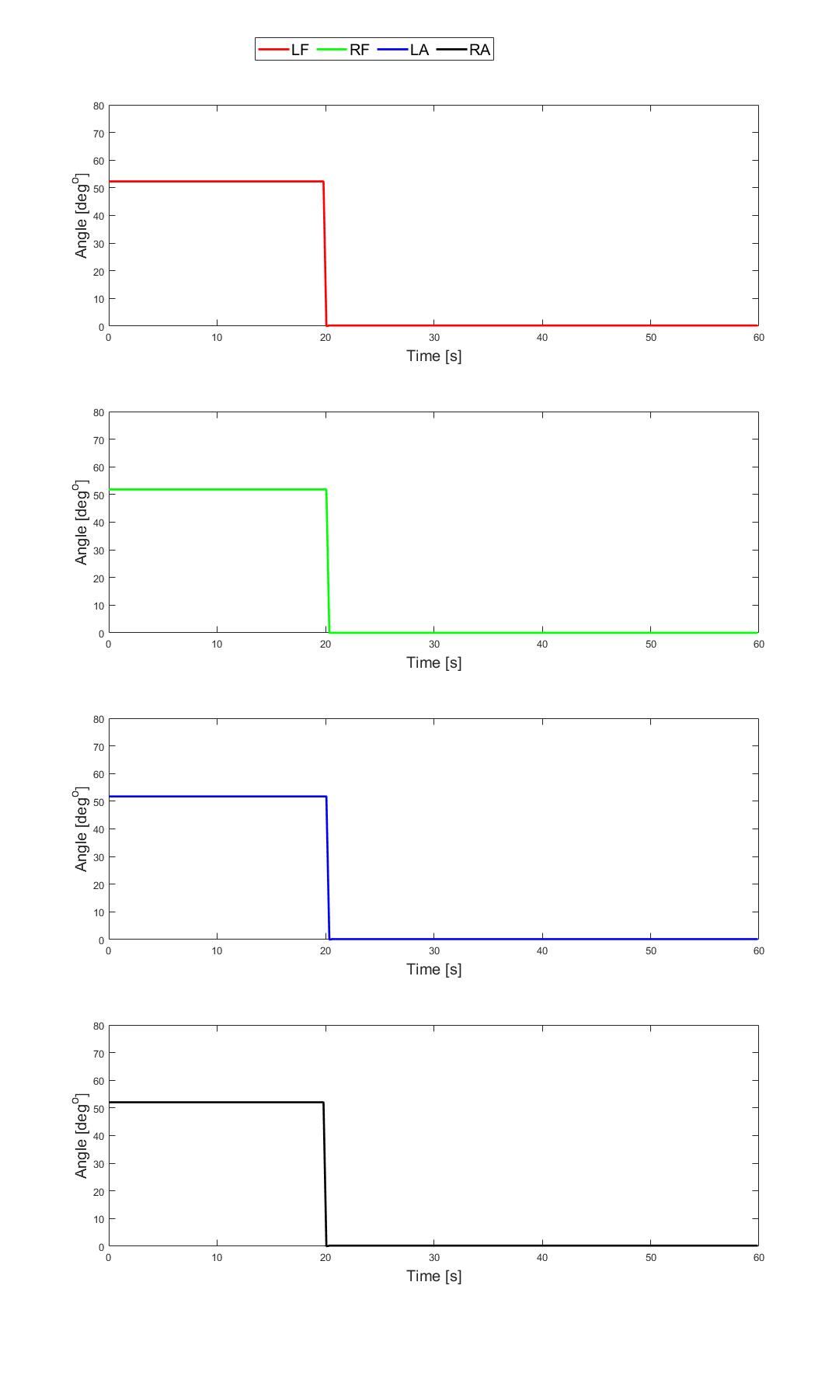
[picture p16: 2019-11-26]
matlab/IEEE_sensors/data_matched/LA,LF,RA,RF/Y/step down1.jpg

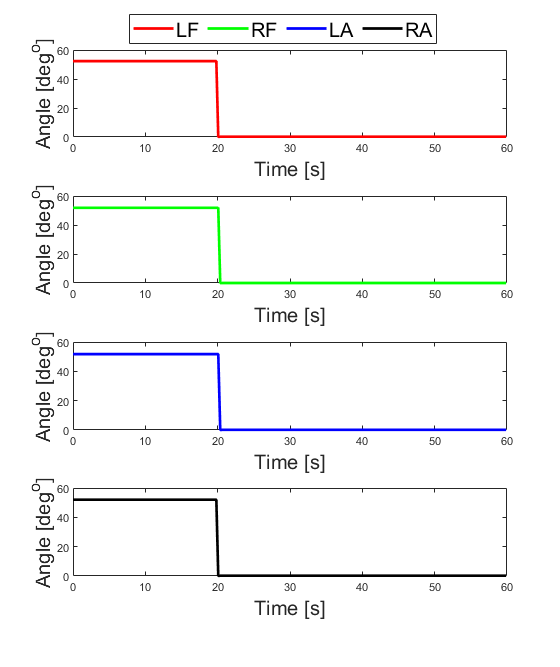
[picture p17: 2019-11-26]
matlab/IEEE_sensors/data_matched/LA,LF,RA,RF/Y/step down.png

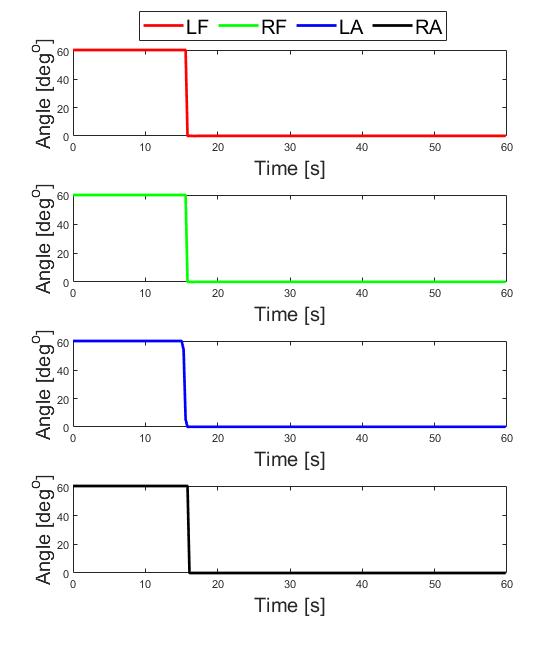
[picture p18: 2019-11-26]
matlab/IEEE_sensors/data_matched/LA,LF,RA,RF/Y/step down_60.jpg

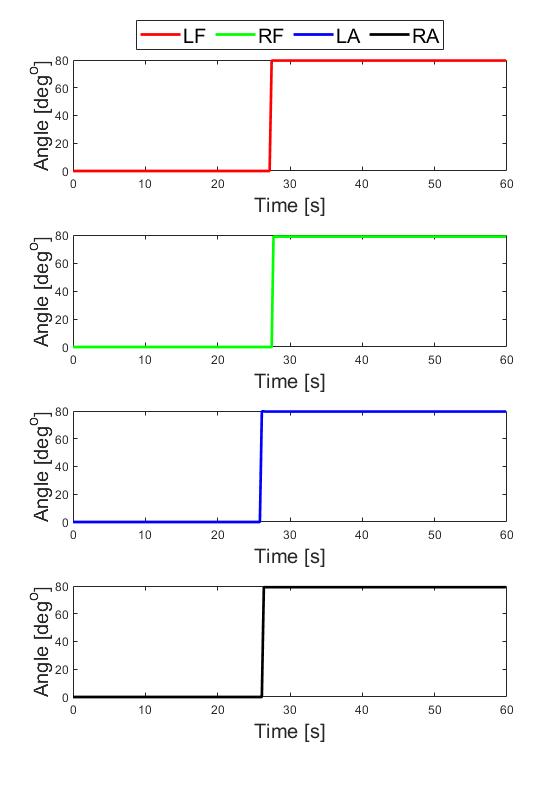
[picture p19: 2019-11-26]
matlab/IEEE_sensors/data_matched/LA,LF,RA,RF/Y/step up_80.jpg

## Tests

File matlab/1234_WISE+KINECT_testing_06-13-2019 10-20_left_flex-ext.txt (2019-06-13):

Timestamp,Kinect_LeftShoulder_Ext.-Flex.,IMU_LeftShoulder_Ext.-Flex.,Kinect_LeftShoulder_Abd.-Add.,IMU_LeftShoulder_Abd.-Add.,Kinect_LeftShoulder_Int.-Ext.,IMU_LeftShoulder_Int.-Ext.,Kinect_LeftElbow_Ext.-Flex.,IMU_LeftElbow_Ext.-Flex.,IMU_LeftElbow_Pro.-Sup.,Kinect_RightShoulder_Ext.-Flex.,IMU_RightShoulder_Ext.-Flex.,Kinect_RightShoulder_Abd.-Add.,IMU_RightShoulder_Abd.-Add.,Kinect_RightShoulder_Int.-Ext.,IMU_RightShoulder_Int.-Ext.,Kinect_RightElbow_Ext.-Flex.,IMU_RightElbow_Ext.-Flex.,IMU_RightElbow_Pro.-Sup.
0.00,0.00,12.14,0.00,0.53,0.00,-18.31,0.00,2.26,-73.96,0.00,-56.26,0.00,-75.67,0.00,4.31,0.00,132.84,4.34
0.36,0.00,6.78,0.00,5.70,0.00,-20.82,0.00,16.84,-73.03,0.00,95.40,0.00,-97.58,0.00,1.02,0.00,131.45,4.35

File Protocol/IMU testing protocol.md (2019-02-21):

# IMU testing protocol

An IMU testing turn-table is built using a goniometer to measure the accuracy of the angle measurements obtained from the IMU sensors. One end of the goniometer is fixed to the table allowing another end of the goniometer to move freely between 0 to 360 degrees. The IMUs soldered to a PCB board are fitted in rectangular 3D printed enclosures, (3D models available in 3D model folder). The IMU enclosures are fixed on the free end of the goniometer for angular movement. The free-end of the goniometer fitted with IMU is restricted for motion about set angles such as (-80, -60, -40, -20, 20, 40, 60, 80) for angle measurement study. The PCB connected with IMUs stream quaternions to the receiver connected to computer for display of angle measurements. A software application using unity3D is developed for streaming the data from receiver through serial communication, convert them to corresponding angle measurements, and display the angle measurements from all the IMUs. 

The software application starts with a user details page where the user can specify relevant information about them such as: subject ID, age group, dexterity, and gender. A start button is present to initialize serial communication and navigate to another page for display of angle measurements. The data being streamed from the IMUs are saved in a text file for further data processing. The nomenclature of the file is defined by the subject ID, time, and date of start of the experiment for easy retrieval and tracking.

The following steps are performed as a protocol for testing of the IMUs:
1.	An executable application generated from the Unity3D is started.
2.	All the PCBs fitted with IMUs are turned on, each have an individual switch.
3.	Stoppers are added at specific locations for specific angles being tested. (E.g. Testing of +80 degrees will require adding stoppers at 0 degrees and 80 degrees.)
4.	The receiver is connected to the computer using USB type-A port.
5.	The user details page is filled with relevant information pertaining to the trial being performed. (E.g. The angle and axis used for testing is entered in the subject ID textbox.)
6.	Click the start button, which redirects the application to another page for display of X, Y, and Z angles of IMUs A, B, C, and D.
7.	The free-end of the goniometer attached with IMUs are moved between desired angle of the trial for measurement. It is repeated to record at least 25 trials, which is also being recorded on a video tape.
8.	The application is enabled with data capture facility and saves it in a text file. 
9.	A matlab script is used to read the text files and extract the measured angles and print them to excel.
10.	 Mean and standard deviation are computed for 20 trials of the measurement.
11.	Plots of the applied angle vs. goniometer measured angle are shown in graph.
12.	The coefficient of determination is used for correlation of the data.

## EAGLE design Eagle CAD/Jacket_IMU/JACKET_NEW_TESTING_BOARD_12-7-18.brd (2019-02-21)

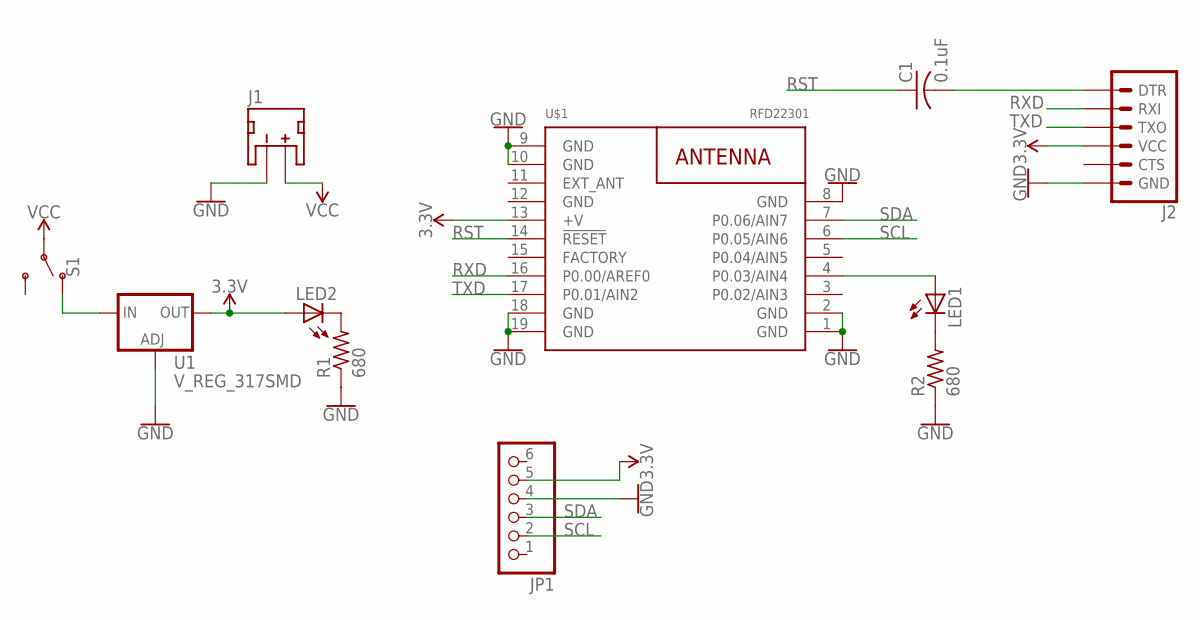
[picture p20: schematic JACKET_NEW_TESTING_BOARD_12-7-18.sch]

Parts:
C1: 0.1uF; C0805
J1: JST_2MM_MALE; JST-2-SMD
J2: 6_PIN_SERIAL_TARGET; 1X06
JP1: PINHD-1X6CB; 1X06-CLEANBIG
LED1, LED2: LEDCHIP-LED0805; CHIP-LED0805
R1, R2: 680; R0805
S1: SWITCH-SPDT-PTH-11.6X4.0MM; SWITCH_SPDT_PTH_11.6X4.0MM
U1: V_REG_317SMD; SOT223
U$1: RFD22301

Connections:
3.3V: J2.4 (VCC), JP1.5, LED2.A, U1.2 (OUT), U$1.13 (+V)
GND: J1.1 (-), J2.6 (GND), JP1.4, R1.1, R2.1, U1.1 (ADJ), U$1.1 (GND), U$1.2 (GND), U$1.8 (GND), U$1.9 (GND), U$1.10 (GND), U$1.12 (GND), U$1.18 (GND), U$1.19 (GND)
unnamed: S1.1 (O), U1.3 (IN)
unnamed: LED2.C, R1.2
unnamed: LED1.C, R2.2
unnamed: LED1.A, U$1.4 (P0.03/AIN4)
unnamed: C1.2, J2.1 (DTR)
RST: C1.1, U$1.14 (!RESET!)
RXD: J2.2 (RXI), U$1.16 (P0.00/AREF0)
SCL: JP1.2, U$1.6 (P0.05/AIN6)
SDA: JP1.3, U$1.7 (P0.06/AIN7)
TXD: J2.3 (TXO), U$1.17 (P0.01/AIN2)
VCC: J1.2 (+), S1.2

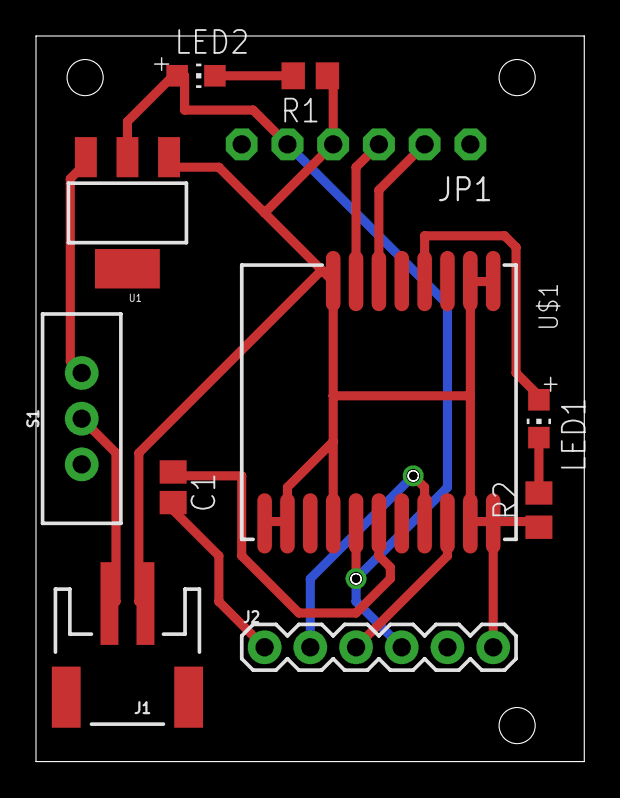
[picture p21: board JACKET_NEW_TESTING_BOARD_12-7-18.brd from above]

Board: 2 copper layers, 30.5 x 40.3 mm, 11 parts (0 on the bottom side), 13 nets.

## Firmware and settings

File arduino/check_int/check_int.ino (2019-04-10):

#include <Wire.h>
byte BNO = 0x28; // BNO055 address
// operation mode registers addresses and values
byte R_OPRmode = 0x3D;
/* remember to mask out the first four bit of previous operation mode because
those four bits are reserved. This mask is done in the BNOmode function */
byte AccMag_mode = B00000100;
byte Config_mode = B00000000;
byte NDOF_mode = B00001100;
byte IMU_mode = B00001000;
byte Gyro_mode = B00000011;

// data registers
/*these values are the register addresses of the least significant byte of
quaternion data, the address of the MSB always follows the LSB*/
byte R_q0 = 0x20;
byte R_q1 = 0x22;
byte R_q2 = 0x24;
byte R_q3 = 0x26;

/*calibration values register*/
byte R_calib = 0x35;
/*variables*/
int q0, q1, q2, q3;
double Q;
String calib_status;
byte calib_acc, calib_gyr, calib_mag, calib_sys;

byte dum;

void setup() {
  Wire.begin();
  Serial.begin(115200);
  while (BNOmode(NDOF_mode)!=0){};
}

void loop() {
  q0 = BNOgetQuat(R_q0);
  q1 = BNOgetQuat(R_q1);
  q2 = BNOgetQuat(R_q2);
  q3 = BNOgetQuat(R_q3);
    if(q0>16384)
  {
    q0= q0 - 65535; 
  }
    if(q1>16384)
  {
    q1= q1-65535; 
  }
    if(q2>16384)
  {
    q2 = q2-65535; 
  }
    if(q3>16384)
  {
    q3= q3 - 65535; 
  }
  Q = (q0*q0+q1*q1+q2*q2+q3*q3)*pow(2,-28);
  Serial.print("q0 = "); Serial.print(q0);
  Serial.print("| q1 = "); Serial.print(q1);
  Serial.print("| q2 = "); Serial.print(q2);
  Serial.print("| q3 = "); Serial.print(q3);
  Serial.print("| Norm = "); Serial.println(Q);
}

/*BNO055 functions*/

byte BNOread(byte R_addr){
  
  byte data;
  bool flag = 0;
  while(flag == 0){
  Wire.beginTransmission(BNO);
  Wire.write(R_addr);
  Wire.endTransmission();
  Wire.requestFrom(BNO,1);
  if (Wire.available()==1){data = Wire.read();
                           flag = 1;}
  }
  return data;
  
  }

byte BNOmode(byte mode){
  
  byte exval;
  byte val;
  byte ok;
  byte flag = 0;
  while (flag <= 1){
  Wire.beginTransmission(BNO);
  Wire.write(R_OPRmode);
  Wire.endTransmission();
  Wire.requestFrom(BNO,1);
  if (Wire.available()==1)
  {
   exval = Wire.read();
   bitClear(exval,0);
   bitClear(exval,1);
   bitClear(exval,2);
   bitClear(exval,3);
   if (flag==0){val = Config_mode|exval;}
   else        {val = (mode|exval);}
   Wire.beginTransmission(BNO);
   Wire.write(R_OPRmode);
   Wire.write(val);
   ok = Wire.endTransmission();
   if (ok == 0){flag += 1;}
   }
    }

  return ok;}

int BNOgetQuat(byte R_addr){
  
  byte MSB, LSB;
  bool flag = 0;
  double q;
  while(flag == 0)
  {
   Wire.beginTransmission(BNO);
   Wire.write(R_addr);
   Wire.write(R_addr+0x1);
   Wire.endTransmission();
   Wire.requestFrom(BNO,2);
   if (Wire.available()==2)
                          { LSB = Wire.read();
                            MSB = Wire.read();
                            q = (int(MSB)<<8)|int(LSB);;
                            flag = 1; }
                                        }

  return q;}

String BNOcalib(){
  
  byte c;
  String calib;
  byte a,m,g,s;
  bool flag = 0;
  while(flag == 0){
  Wire.beginTransmission(BNO);
  Wire.write(R_calib);
  Wire.endTransmission();
  Wire.requestFrom(BNO,1);
  if (Wire.available()==1)
  {c = Wire.read();
   m = bitRead(c,1); m = (m<<1)+bitRead(c,0);
   a = bitRead(c,3); a = (a<<1)+bitRead(c,2);
   g = bitRead(c,5); g = (g<<1)+bitRead(c,4);
   s = bitRead(c,7); s = (s<<1)+bitRead(c,6);
   calib = "acc "+String(a)+" mag "+String(m)+" gyr "+String(g)+" sys "+String(s);
   flag = 1;}
  }
  return calib;}

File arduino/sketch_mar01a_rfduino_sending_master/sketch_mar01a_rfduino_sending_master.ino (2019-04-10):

#include <RFduinoGZLL.h>
#include <Wire.h>
device_t role = DEVICE4;
byte BNO = 0x28; // BNO055 address
byte R_OPRmode = 0x3D;
byte R_PWRmode = 0x3E;
/* remember to mask out the first four bit of previous operation mode because
those four bits are reserved. This mask is done in the BNOmode function */
byte AccMag_mode = B00000100;
byte Config_mode = B00000000;
byte NDOF_mode = B00001100;
byte IMU_mode = B00001000;
byte Gyro_mode = B00000011;
byte resetregister = 0x3F;

// data registers
/*these values are the register addresses of the least significant byte of
quaternion data, the address of the MSB always follows the LSB*/
byte R_q0 = 0x20;
byte R_q1 = 0x22;
byte R_q2 = 0x24;
byte R_q3 = 0x26;

/*calibration values register*/
byte R_calib = 0x35;
/*variables*/
int w, x, y, z;
double Q;
String calib_status;
byte calib_acc, calib_gyr, calib_mag, calib_sys;
byte c,m,a,g,s;  
byte dum;
String final="";
void setup() {
    Serial.begin(115200); 
  RFduinoGZLL.begin(role);
      Serial.print("Setup");
  RFduinoGZLL.txPowerLevel=4;
  Serial.print("flg1");
  pinMode(3,OUTPUT);
  Serial.print("flg1");
  // put your setup code here, to run once:
  while (BNOmode(Config_mode)!=0){    Serial.print("flg2");};  
      Serial.print("flg3");
delay(25);

  resetPWR();
    Serial.print("Power reset");
  delay(25);
  resetIMU();
      Serial.print("IMU reset");
  delay(25);
  Wire.begin();
  Serial.print("Setup");
  
while (BNOmode(NDOF_mode)!=0){};
Serial.print("NDOF ON");
  
}

void loop() {
  // put your main code here, to run repeatedly: 
int16_t q0 = BNOgetQuat(R_q0);
int16_t q1 = BNOgetQuat(R_q1);
int16_t q2 = BNOgetQuat(R_q2);
int16_t q3 = BNOgetQuat(R_q3);
//double w = double(q0)*pow(2,-14);
//double x = double(q1)*pow(2,-14);
//double y = double(q2)*pow(2,-14);
//double z = double(q3)*pow(2,-14);
//Q = w*w+x*x+y*y+z*z;
w = map(q0,-16384,16384,0,200);
x = map(q1,-16384,16384,0,200);
y = map(q2,-16384,16384,0,200);
z = map(q3,-16384,16384,0,200);
final="";
final="c,"+String(w)+","+String(x)+","+String(y)+","+String(z)+"\n";
Serial.print(final);
char mydata[final.length()+1];
final.toCharArray(mydata,final.length()+1);
RFduinoGZLL.sendToHost(mydata,final.length()+1);
digitalWrite(3,HIGH);
delay(random(10,25));
//Serial.print(w);Serial.print(", ");Serial.print(x);Serial.print(", ");Serial.print(y);Serial.print(", ");Serial.print(z);Serial.print(", ");Serial.println(Q);
//Serial.print(q0);Serial.print(", ");Serial.print(q1);Serial.print(", ");Serial.print(q2);Serial.print(", ");Serial.println(q3);

}

byte BNOmode(byte mode){
  
  byte exval;
  byte val;
  byte ok;
  byte flag = 0;
  bool flg=1;
  while (flag <= 1){
  Wire.beginTransmission(BNO);
  Wire.write(R_OPRmode);
  flg = Wire.endTransmission();
  if(flg==0){Serial.print("flg=0");}
  Wire.requestFrom(BNO,1);
  if (Wire.available()==1)
  {
   exval = Wire.read();
   bitClear(exval,0);
   bitClear(exval,1);
   bitClear(exval,2);
   bitClear(exval,3);
   if (flag==0){val = Config_mode|exval;}
   else        {val = (mode|exval);}
   Wire.beginTransmission(BNO);
   Wire.write(R_OPRmode);
   Wire.write(val);
   ok = Wire.endTransmission();
   if (ok == 0){flag += 1;}
   }
    }

  return ok;}


void resetIMU()
{
  bool ok = 1;
  while (ok==1){
  byte resetinfo = BNOread(resetregister);
  bitClear(resetinfo,6);
  Wire.beginTransmission(BNO);
  Wire.write(resetinfo);
  delay(10);
  bitSet(resetinfo,6);
  bitSet(resetinfo,8);
  Wire.beginTransmission(BNO);
  Wire.write(resetinfo);
  delay(10);
  Wire.endTransmission();
  Wire.beginTransmission(BNO);
  Wire.write(resetregister);
  Wire.write(0x80);
    delay(10);
  ok = Wire.endTransmission();
  }
  return;
}


void resetPWR()
{
  bool ok = 1;
  while (ok==1){
  Wire.beginTransmission(BNO);
  Wire.write(R_PWRmode);
  Wire.write(0x00);
  delay(10);
  ok = Wire.endTransmission();
  }
  return;
}

byte BNOread(byte R_addr){
  
  byte data;
  bool flag = 0;
  while(flag == 0){
  Wire.beginTransmission(BNO);
  Wire.write(R_addr);
  Wire.endTransmission();
  Wire.requestFrom(BNO,1);
  if (Wire.available()==1){data = Wire.read();
                           flag = 1;}
  }
  return data;
  
  }

  String BNOcalib()
  {
  byte c;
  String calib;
  byte a,m,g,s;
  bool flag = 0;
  while(flag == 0){
  Wire.beginTransmission(BNO);
  Wire.write(R_calib);
  delay(25);
  Wire.endTransmission();
  Wire.requestFrom(BNO,1);
  if (Wire.available()==1)
  {c = Wire.read();
   m = bitRead(c,1); m = (m<<1)+bitRead(c,0);
   a = bitRead(c,3); a = (a<<1)+bitRead(c,2);
   g = bitRead(c,5); g = (g<<1)+bitRead(c,4);
   s = bitRead(c,7); s = (s<<1)+bitRead(c,6);
   calib = "acc "+String(a)+" mag "+String(m)+" gyr "+String(g)+" sys "+String(s);
   flag = 1;}
  }
  return calib;
  }

int16_t BNOgetQuat(byte R_addr){
  
  byte MSB, LSB;
  bool flag = 0;
  int16_t q;
  while(flag == 0)
  {
   Wire.beginTransmission(BNO);
   Wire.write(R_addr);
   Wire.write(R_addr+0x1);
   Wire.endTransmission();
   Wire.requestFrom(BNO,2);
   if (Wire.available()==2)
                          { LSB = Wire.read();
                            MSB = Wire.read();
                            q = (int16_t(MSB)<<8)|int16_t(LSB);
                            flag = 1; }
                                        }

  return q;}

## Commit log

2019-02-20 New folders with data, 3D Model, and Arduino scripts have been added
2019-02-20 Added data,3D model, and arduino scripts
    [+10 degree data.xlsx, +20 degree data.xlsx, +40 degree data.xlsx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]
2019-02-21 protocol for IMU testing added
2019-02-21 Updated data file with X axis plots
    [angleerror_C.xlsx]
2019-02-21 Added EAGLE CAD Drawings
    [JACKET_NEW_TESTING_BOARD_12-7-18.brd, JACKET_NEW_TESTING_BOARD_12-7-18.sch]
2019-02-21 Added a .md file of the IMU protocol
2019-02-25 new file arduino i2c comunication without library
2019-02-25 matlab codes for i2c communication with BNO055 single and multiple
2019-02-26 Completed the IMU code with absolute orientation compatible with RFduino
2019-03-16 Final version of the RFduino script with IMU
2019-03-27 Kinect supplementary files for matlab with Kinect joint angle assessment script
    [fullMeanHead60_tri.ply]
2019-04-02 Added new 3D model with switch opening, lighting opening
    [Assem1.SLDASM, Assem1.SLDDRW, bottom.SLDPRT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]
2019-04-02 .STL files added
    [bottom.STL, top.STL]
2019-04-05 Changed dimension based on looking at the actual 3D print
    [Assem1.SLDASM, Assem1.SLDDRW, bottom.SLDPRT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]
2019-04-10 <ac_tpose has the transformation necessary to transform imu a as back imu >
2019-04-10 Kinect+IMU's combined partially working, created a new data saving directory
    [bottom.SLDPRT, wearable+kinecttesting_04-10-2019 04-21.xlsx, wearable+kinecttesting_04-10-2019 04-25.xlsx]
2019-04-12 Added Calibration UI and Unity Scene
2019-04-14 Kinect + IMU & Quaternion codes updated
    [testing2_1042019.xlsx, testing_10-4-2019.xlsx]
2019-04-25 calibration box
    [box.SLDPRT]
2019-04-25 calibration box stl
    [calibration_box.STL]
2019-04-28 Modified version of Kinect with IMU
    [Assem1.SLDASM, Assem1.SLDDRW, bottom.SLDPRT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]
2019-05-26 Updated kinect and IMU code
2019-05-30 new design
    [case.ipt, case.stl, door.ipt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]
2019-05-31 assemblies new
    [Assieme1.stl, Assieme2.stl]
2019-06-03 Revised Kinect+IMU integration code
    [wearable+kinecttesting_04-10-2019 04-21.xlsx, wearable+kinecttesting_04-10-2019 04-25.xlsx]
2019-06-11 new design final
    [calibration_box.ipt, calibration_box.stl, holderH.ipt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]
2019-06-13 Unity Code Updated with Dynamic PlayBack
    [Right.obj, fullMeanHead60_tri.ply]
2019-06-14 Completed version of the code for Kinect IMU comparison
2019-06-14 Replaced files
    [fullMeanHead60_tri.ply]
2019-06-17 stl model
    [A_door.stl, B_door.stl, C_door.stl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]
2019-06-20 New IMU boxes and codes fixed
2019-06-21 match coordinate frames
2019-06-21 Added entire unity project
    [Banana.obj, BoxesOBJ.obj, Modern stressed table.obj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]
2019-06-25 static offset and mounting fixing
2019-07-01 single patient toroid function plot
2019-07-09 Data for A sensor
2019-07-09 Data for B,C,D sensor
2019-07-10 kinect ie algorthm for imu
2019-07-10 New code for all WISE sensors measurement in turntable
2019-07-12 Image drawing + data + other codes IEEE ISMB
    [turntablepeaks _analysis.xlsx]
2019-07-14 edited match frame function
2019-07-22 Removed Unity Code, Check the New Repository for the Updated Unity Code
    [Banana.obj, BoxesOBJ.obj, Modern stressed table.obj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]
2019-07-27 change get left and right for imu int ext sho rot
2019-07-29 WISE design
    [H_holder.stl, V_holder.stl, case3_L.stl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]
2019-07-30 New codes for IEEE sensors
2019-07-31 IEEE Sensors
2019-07-31 animated line of mounting offset and internal external
2019-08-03 Data analysis excel sheet updated
    [final data.xlsx]
2019-08-07 codes for testing IEEE sensors
2019-08-10 Data for IEEE sensors paper processed
    [dataanalysis.xlsx, dataanalysis_peaks.csv, final data.xlsx]
2019-08-23 Repeatability and accuracy analysis
    [dataanalysis.xlsx, dataanalysis_peaks.csv]
2019-08-23 Repeatability and accuracy for IEEEsensors
    [dataanalysis.xlsx]
2019-09-01 Updated data collection and results for mHealth
    [Wearable Inertial Sensors for Exergames (post survey)_August 31, 2019_11.58.csv, Wearable Inertial Sensors for Exergames (post survey)_August 31, 2019_11.58.xl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]
2019-09-24 Bland Altman with Kimber
    [Wearable Inertial Sensors for Exergames (post survey)_August 31, 2019_11.58.xlsx, final_dtw_normalized(AutoRecovered).xlsx, final_dtw_normalized.xlsx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]
2019-09-25 Cronbach alpha, Bland-Altman, Data plotting
    [Wearable Inertial Sensors for Exergames (post survey)_August 31, 2019_11.58.xlsx]
2019-09-26 Cronbach alpha + Bland-Altman
    [Wearable Inertial Sensors for Exergames (post survey)_August 31, 2019_11.58.xlsx]
2019-10-29 Exergame adaptation loop simulation
    [Wearable Inertial Sensors for Exergames (post survey)_August 31, 2019_11.58.xlsx, lookup.xlsx]
2019-11-26 Comments plots for IEEE sensors
    [0 degree.xlsx, 0_final.csv, 0_final1.csv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]
2019-12-03 IEEE sensors stable plots
    [0-90-180degrees.csv, 0_final_mp.csv, 0_final_mp.xlsx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]

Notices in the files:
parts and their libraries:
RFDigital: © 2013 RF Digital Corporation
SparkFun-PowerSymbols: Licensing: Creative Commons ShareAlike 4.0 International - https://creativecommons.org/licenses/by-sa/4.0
